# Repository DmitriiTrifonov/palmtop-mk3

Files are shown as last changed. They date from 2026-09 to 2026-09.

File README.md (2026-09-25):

# Palmtop Mk3

A clamshell that turns a Pixel 3a XL into a pocketable laptop-shaped terminal.
Third iteration, after Mk1 (Blender) and Mk2 (FreeCAD), neither of them published.

Same phone, new keyboard — a Jomaa KEYBOARD098RU salvaged from its folio case.

<p align="center">
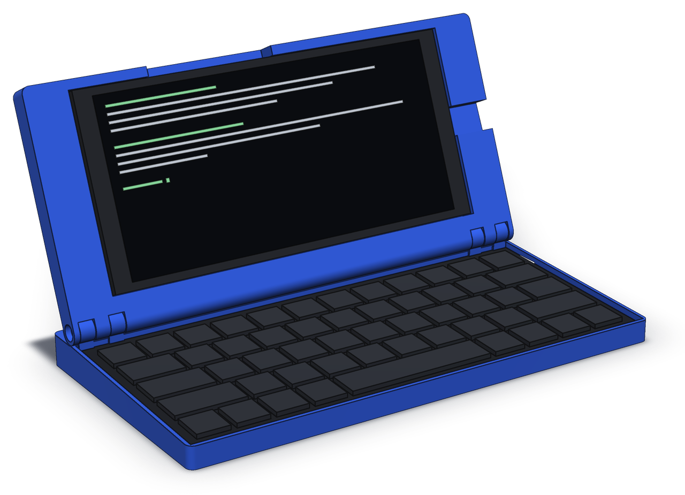
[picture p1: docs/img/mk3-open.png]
Palmtop Mk3 open at 112 degrees: a blue printed clamshell, the phone in the lid showing a terminal, the keyboard in the base
  
</p>

**The goal of Mk3 is to be as thin as possible.** Mk2 is roughly 32 mm closed;
Mk3's design point is 22.2 mm, with both components fully enclosed and the
keyboard never opened.

<p align="center">
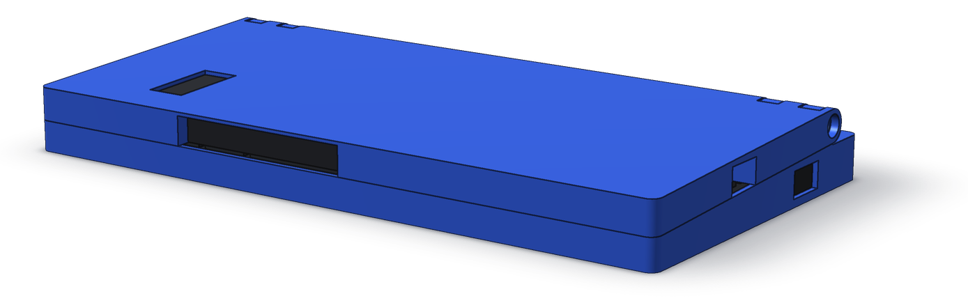
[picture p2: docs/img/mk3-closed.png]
Palmtop Mk3 closed, seen from the front right
  
  <br>
  <sub>Shut: 22.24 mm at the hinge, 18.26 at the front. Both renders come straight from the
  model via <code>cad/render.py</code>; the phone and keyboard are stand-ins built from
  their measured envelopes.</sub>
</p>

## Status

Measured, analysed, modelled, and now printing. The geometry is code — `cad/`
builds and self-verifies against the analyses — and the first printed coupons
caught two defects that no check could see, both of which are now checked for:
see [ADR-0010](docs/adr/0010-hinge-station-count.md).

**Design point: 22.24 mm closed at the rear, 18.26 at the front** — the keyboard
is a 2.64 deg wedge, so the closed device is one too.

| Doc | What it is |
|---|---|
| [requirements.md](docs/requirements.md) | Goals, constraints, acceptance criteria |
| [measurements.md](docs/measurements.md) | Every number, with a confidence tag |
| [analysis/thickness-budget.md](docs/analysis/thickness-budget.md) | Where the closed height goes, and three scenarios |
| [analysis/balance.md](docs/analysis/balance.md) | Whether the heavy lid tips it over, and what it costs to fix |
| [analysis/clamshell-geometry.md](docs/analysis/clamshell-geometry.md) | Why the lid is shallower than the base and the tail stays exposed |
| [plan.md](docs/plan.md) | Phases, critical path, and the five named risks |
| [parameters.md](docs/parameters.md) | Every driving dimension, paired with `cad/params.py` |
| [adr/](docs/adr/README.md) | Ten design decisions: six accepted, one rejected, three open |

## Findings so far

**Neither component gets thinner, so the skins had to go.** The keyboard shell is
9.52 mm and the phone 8.2 mm; together that is 90% of the budget and neither is
negotiable — [ADR-0002](docs/adr/0002-keyboard-integration-depth.md) keeps the
keyboard sealed and defers stripping it to Mk4. What remained were two 1.2 mm
skins: the lid's back and the base's floor. Deleting both is what gets the device
under 20 mm.

**Both skins were spent on enclosure, deliberately.** Neither was structurally
necessary: the keyboard's own bottom shell could have been the base's floor
(-1.2 mm), and the phone's own back could have been the lid's outer face
(-1.2 mm), for a 19.8 mm device with both components exposed.
[ADR-0008](docs/adr/0008-base-floor.md) and
[ADR-0004](docs/adr/0004-phone-retention.md) declined both. The result is 22.24 mm
with everything enclosed — a 30% reduction over Mk2 instead of 38%. That was the
trade, and it leaves only 0.26 mm against the current hard limit, which
[needs restating](docs/requirements.md#n1-needs-restating).

**The hinge is printed, not bought.** Holding the lid takes 0.10-0.12 N*m — the
very bottom of the commercial torque-hinge range, where Reell's scaled-down
consumer-electronics series starts at 0.11 N*m. Printed knuckles on two M3 bolted
stations deliver it at 22-25 N of clamp each, still a light load for an M3. The governing idea is that **the bolt sets deflection and a
compliant washer sets force**, so the setting is adjustable with a screwdriver
and survives PETG creep. Stations rather than a full-width rod, because racking
resistance comes from the span between the outermost points, not from continuity
— and a 193 mm printed barrel would bow. Two stations rather than three because
a bolt can only reach a station from outside the device: the lid's rounded rear
runs the full width along the hinge axis, so a centre station had no way in
([ADR-0010](docs/adr/0010-hinge-station-count.md)). No lead time, which took the longest
item off the critical path. Purchased torque hinges stay recorded as an upgrade
path in [ADR-0005](docs/adr/0005-hinge-mechanism.md).

**The tipping problem turned out to be free to fix.** The phone (167 g) outweighs
the keyboard (95 g) and the device tips past 127 deg of opening unaided. Fixing
it entirely — no tipping at any angle — costs 15 mm of rear setback, which is
zero mass and zero thickness — and the same 15 mm is where the hinge stations
stand. Nothing like the
substantial ballast that Mk2's `palmtop_weighted` name implies.

## Layout

```
docs/          requirements, measurements, analyses, ADRs
docs/img/      README renders, from cad/render.py
cad/           build123d model: params.py drives it, build.py checks and exports
export/        STL and STEP for printing, SVG drawings
```

## Licence

Copyright Dmitrii Trifonov 2026.

The design — the model in `cad/`, the files it exports, and the documentation — is
released under the [CERN Open Hardware Licence Version 2 – Strongly Reciprocal](LICENSE)
(CERN-OHL-S-2.0). Under this licence the Python model is the design's source: if
you adapt it, to a different phone or keyboard say, and distribute the result or
anything built from it, you share your modified source under the same terms.

Source location: <https://github.com/DmitriiTrifonov/palmtop-mk3>

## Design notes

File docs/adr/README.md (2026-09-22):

# Architecture decision records

One file per structural decision, written before the geometry is committed to
CAD. See [ADR-0001](0001-record-architecture-decisions.md) for why.

| # | Decision | Status | Blocked on |
|---|---|---|---|
| [0001](0001-record-architecture-decisions.md) | Record design decisions as ADRs | Accepted | — |
| [0002](0002-keyboard-integration-depth.md) | How deeply to integrate the keyboard | **Accepted** — stays sealed, stripping deferred to Mk4 | — |
| [0003](0003-lid-balance-strategy.md) | Keeping the device from tipping backwards | **Accepted** — 15 mm rear setback + empty ballast pocket |
| [0004](0004-phone-retention.md) | How the phone is held in the lid | **Accepted** — closed pocket with a rear wall | — |
| [0005](0005-hinge-mechanism.md) | Hinge mechanism | Proposed | Coupon 2.2 — measured torque of a printed bolted hinge |
| [0006](0006-rear-edge-io-vs-hinge.md) | Keyboard I/O on the hinge edge | **Rejected** — the premise was a misread photograph | — |
| [0007](0007-cad-toolchain.md) | CAD toolchain | **Accepted** — build123d, model is Python in `cad/` |
| [0008](0008-base-floor.md) | Base floor | **Accepted** — full 1.2 mm floor kept; Option E open | Task 0.4 (Option E only) |
| [0009](0009-closure-retention.md) | Keeping the device shut when closed | Proposed | Coupon 2.2 — does hinge torque survive 100 cycles |
| [0010](0010-hinge-station-count.md) | How many hinge stations, and how a bolt reaches its pocket | Proposed — two stations, heads outboard | First article — does the lid sag at mid-span |

## Dependency order

```
0002 (keyboard sealed, ACCEPTED)
   |
   +--> only two 1.2 mm skins left as thickness levers, both now spent:
   |        0008 (base floor, ACCEPTED: kept)
   |        0004 (lid rear wall, ACCEPTED: kept)   --> 22.24 mm
   |            |
   |            +--> 0008 Option E (0.8 ribbed floor) is the last 0.4 mm
   |
   +--> 0006 (rear I/O stays a live problem)
            |
   0005 (hinge) <--> 0003 (setback) <--> 0006 (rear I/O)
        all three resolve into one rear-edge cross-section
            |
            +--> 0009 (stays shut) rides on 0005's measured torque

0007 (toolchain) gates everything but depends on nothing
```

## The shape of the design as it stands

0002 fixed the keyboard as an untouchable 9.52 mm block, leaving two 1.2 mm skins
as the only thickness levers. 0008 spent one on an enclosed base; 0004 spent the
other on a protected phone back, the fingerprint reader it covers being unused.

The result is **22.24 mm** — a 30% reduction over Mk2 with both components fully
enclosed, rather than the 38% that was available with both exposed. That was the
trade, made twice and deliberately.

**It leaves 0.26 mm of margin against N1's hard limit of 22.5, which is not a
margin.** Two things follow: 0008 Option E (a 0.8 ribbed floor, stiffer than the
flat 1.2 it replaces) is now the project's only remaining reduction and should be
resolved early; and the hard limit itself needs restating, since 22.5 was derived
from an early estimate of this very scenario.

On balance, the two decisions nearly cancelled: 0008 added 26 g low, 0004 added
25 g high, and the device tips at 127 deg. A **15 mm** rear setback eliminates
tipping at any angle across the whole plausible mass bracket — 11 mm covered only
the expected case — and 0006 uses that tail as a shelf for the keyboard's
rear-edge I/O.

So the three open structural ADRs remain one problem: **the rear-edge
cross-section**, where the hinge, the setback and the keyboard's switch, LEDs and
USB-C all have to share the same 15 mm of depth.

0005 has since made that section easier in two ways. Its printed knuckles on
bolted stations have **no lead time**, so they no longer block the drawing; and
because the stations occupy points rather than the whole rear line, the gaps
between them are free for port tunnels. What is left blocking the cross-section
is a single measurement, task 0.1.

0009 turned out to need no hardware of its own. Holding the lid shut while
inverted takes the same 0.091 N*m as holding it at 90 deg — the moment arm is the
same in both cases — so the hinge torque F3 already demands satisfies F8 with
margin. Magnets stay recorded as insurance, with a note to check the phone's
magnetometer first.

One more consequence surfaced along the way and is written up in
[clamshell-geometry.md](../analysis/clamshell-geometry.md): with an inboard axis,
a lid the same depth as the base **does not open at all** — its rear overhang
drives straight into the setback tail. The lid is therefore 197 x 90 and the base
197 x 105, with the tail exposed even when shut, exactly as a laptop's hinge
region is. Full 0-180 deg remains available.

0010 came out of a question asked while looking at an assembly drawing: would the
bolt actually go in? It would not. The lid's rounded rear is a solid cylinder
coaxial with the hinge, so it blocks the bolt's path equally at every opening
angle, and the centre station had no path at all. Neither the interference check
nor the 0-180 deg sweep could see it — an unassemblable joint overlaps nothing.
The station count dropped to two and `build.py` gained a corridor check, next to
the connectivity check added the same day for the same class of blindness.

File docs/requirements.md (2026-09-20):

# Requirements

## Context

Palmtop Mk3 is the third iteration of a clamshell that turns a Pixel 3a XL into a
pocketable laptop-shaped terminal. Mk1 (`../pixel_palmtop`, Blender) and Mk2
(`../palmtop_mk2`, FreeCAD) both worked, but Mk2 is bulky: a 170 x 91.4 footprint
with a base part 23.35 tall and a lid part 18.21 tall.

Mk3 keeps the same phone and swaps in a much slimmer keyboard (Jomaa
KEYBOARD098RU, salvaged from its folio case).

## Primary goal

**Minimise closed thickness.** Every other property is negotiable against it,
within the constraints below.

## Functional requirements

| # | Requirement |
|---|---|
| F1 | Holds a Pixel 3a XL in landscape orientation in the lid, screen facing the keyboard when closed |
| F2 | Holds the Jomaa keyboard in the base |
| F3 | Opens and stays open, hands-free, at any angle within the supported range |
| F4 | Does not tip over backwards at any supported opening angle, on a desk |
| F5 | Keyboard USB-C reachable without disassembly. The power switch stays permanently ON and needs no access in normal use; the status LEDs are not required to be visible |
| F6 | Phone USB-C reachable for charging while the device is open and in use |
| F7 | **Relaxed.** The phone is taped into the lid, as Mk2's was, so it comes out with a pry and some patience rather than in 30 seconds. An accepted trade, not a requirement met — see [ADR-0004](adr/0004-phone-retention.md) |
| F8 | Stays shut when closed, including inverted in a bag — see [ADR-0009](adr/0009-closure-retention.md) |

## Non-functional requirements

| # | Requirement |
|---|---|
| N1 | Closed thickness at the thickest point: target <= 20.0, hard limit <= 22.5. Design point is **22.24** — the target is missed by 2.24 through two deliberate trades, [ADR-0008](adr/0008-base-floor.md) and [ADR-0004](adr/0004-phone-retention.md). **The hard limit needs restating** (see below) |
| N2 | Footprint: base ~197 x 105 including the 15 mm rear setback; lid ~197 x 90, ending at the hinge axis, leaving the tail exposed when closed (see [clamshell geometry](analysis/clamshell-geometry.md)) |
| N3 | Printable on a 256 x 256 bed without the base being split into multiple parts |
| N4 | Total mass <= 400. Currently ~374 as printed (~432 if it were solid) — measure against the slicer's figure, not `volume x density` |
| N5 | No custom electronics — keyboard and phone stay stock |
| N6 | Parametric CAD: all key dimensions driven from one table, so a different phone or keyboard is a re-parametrisation, not a redraw. Satisfied by [ADR-0007](adr/0007-cad-toolchain.md) — `docs/parameters.md` paired with `cad/params.py` |

## Explicit non-goals

- Modifying the phone or flashing anything on it
- Adding a trackpad, extra battery or any powered component
- Water or drop resistance beyond "survives being carried in a bag"

## Acceptance criteria

The build is done when all of the following hold on the physical device:

1. Closed thickness measured at the thickest point is within N1.
2. The open device does not tip backwards when the lid is at the maximum
   supported angle and the screen is tapped firmly at its top edge.
3. The lid holds position at 100, 120 and the maximum supported angle after
   50 open/close cycles.
4. Keyboard can be charged and power-cycled with the device fully assembled.
5. Phone can be charged with the device open and in use.
6. Phone can be removed and reinserted without damaging either the phone or the
   lid. Not quickly — F7 was relaxed when the phone went onto tape.

## N1 needs restating

The hard limit of 22.5 was written before any construction was chosen, as a round
number just above an early estimate of what is now the selected scenario. The
device has landed at 22.24, so the limit constrains with 0.26 mm of margin — and
it is constraining against a number derived from itself.

This matters because the contingency is real: if coupon 2.4 shows the base flexes
under typing, the floor goes from 1.2 to 2.0-2.5 and the device becomes 23.0-23.5.
There is no headroom to absorb that.

Two responses, not exclusive:

1. Pursue [ADR-0008](adr/0008-base-floor.md) Option E — a 0.8 floor ribbed into
   the keyboard's rim recess, which is *stiffer* than the flat 1.2 it replaces
   and gives back 0.4. This is the project's only remaining reduction.
2. Replace 22.5 with a limit that means something — a pocket, a bag sleeve, a
   number the owner actually cares about — rather than one back-derived from a
   spreadsheet.

**Open question for the owner:** what is the real ceiling?

## Scope boundary with Mk4

[ADR-0002](adr/0002-keyboard-integration-depth.md) keeps the keyboard sealed for
Mk3. Stripping it to its bare plate — worth an estimated 16.5-18.5 mm closed, but
irreversible on the only unit in hand — is deferred to Mk4, to be attempted once
a working Mk3 exists as a fallback. Mk3 must therefore leave the keyboard
removable without cutting anything.

## Open decisions

See [the ADR index](adr/README.md). ADR-0002 is settled; the remaining structural
decisions are not. The analyses in `docs/analysis/` exist to inform them.

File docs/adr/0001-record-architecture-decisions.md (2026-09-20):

# ADR-0001: Record design decisions as ADRs

- **Status:** Accepted
- **Date:** 2026-09-20

## Context

Mk1 and Mk2 exist only as CAD files. The reasoning behind their geometry — why
the footprint is 170 x 91.4, why the base is 23 mm tall, what the "weighted" in
`palmtop_weighted_mk2` was compensating for — is gone. Mk3 starts by re-deriving
things that were presumably already understood two iterations ago.

## Decision

Every structural decision for Mk3 is recorded as a numbered ADR in `docs/adr/`,
written before the geometry is committed to CAD. An ADR stays `Proposed` until
the supporting measurement or test print exists.

## Consequences

- A decision that is later reversed leaves a trail explaining why it was made,
  which is the expensive part to reconstruct.
- ADRs are immutable once `Accepted`. A changed mind is a new ADR that supersedes
  the old one, not an edit.
- Numbers quoted in an ADR must carry a confidence tag from
  [measurements.md](../measurements.md), so a decision resting on a guess is
  visibly resting on a guess.

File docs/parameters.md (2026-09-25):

# Parameters

**Generated from `cad/params.py` — do not edit by hand.**
Regenerate with `.venv/bin/python cad/gen_params_doc.py`.

The Python is the source of truth; this file exists so the numbers are readable
and reviewable in a diff, as [ADR-0007](adr/0007-cad-toolchain.md) requires.

All lengths mm, masses g, angles deg.

Status: `M` measured · `S` from spec · `D` decided in an ADR · `C` calculated
from others here · `A` assumed, not yet verified

---

## Keyboard — Jomaa KEYBOARD098RU

| Name | Value | St | Note |
|---|---|---|---|
| `kbd_span_x` | 194 | M |  |
| `kbd_depth_y` | 86.25 | M |  |
| `kbd_h_rear` | 9.52 | M | thickest, rear of the wedge |
| `kbd_h_front` | 5.54 | M | thinnest, front |
| `kbd_keycap_rear` | 1.82 | M |  |
| `kbd_keycap_front` | 1.82 | M | owner: same as rear |
| `kbd_mass` | 95 | M |  |
| `kbd_rim_width` | 1.68 | M | perimeter rim on the underside |
| `kbd_wedge_angle` | 2.642 | C | atan((h_rear - h_front) / depth) |

## Keyboard USB-C — on the RIGHT SIDE face, not the rear edge

| Name | Value | St | Note |
|---|---|---|---|
| `kbd_usbc_rear_inset` | 8 | M | rear edge to the near end of the connector |
| `kbd_usbc_z_bottom` | 3 | M | opening's lower edge above the rest plane |
| `kbd_usbc_z_top_inset` | 2 | M | opening's upper edge below the top of that face |
| `kbd_usbc_face_h` | 8.9432 | C | the side face is a wedge |
| `kbd_usbc_h` | 3.9432 | C | derived opening height |
| `kbd_usbc_w_ASSUMED` | 9 | A | task 0.1 — the last measurement outstanding |
| `usbc_centre_y` | 75.65 | C | in device coordinates |
| `usbc_centre_z` | 6.1716 | C |  |
| `usbc_cut_w` | 13 | D | opening in the base's right wall, along Y |
| `usbc_cut_h` | 7.5 | D | along Z |

## Phone — Pixel 3a XL

| Name | Value | St | Note |
|---|---|---|---|
| `phone_x` | 160.1 | S | long axis, horizontal in the lid |
| `phone_y` | 76.1 | S |  |
| `phone_z` | 8.2 | S | body, excluding the camera bump |
| `phone_mass` | 167 | S |  |
| `phone_front_wall` | 4 | D | biased forward so the buttons are reachable |
| `tape_t` | 1 | D | double-sided tape, on the pocket's SIDE walls |
| `button_win_x0` | -48.6 | M | button window, from Mk2's STL |
| `button_win_x1` | 5 | M |  |
| `cam_x0` | -69.8 | M | camera cutout, from Mk2's STL |
| `cam_x1` | -58.6 | M |  |
| `cam_from_edge0` | 8.85 | C | referenced to the phone's own button-side edge |
| `cam_from_edge1` | 32.05 | C |  |
| `phone_usbc_cut_w` | 12 | D | phone's own port, lid's right wall |
| `phone_usbc_cut_h` | 7 | D |  |

## Materials and clearances

| Name | Value | St | Note |
|---|---|---|---|
| `mat_density` | 0.00127 | S | g/mm3, PETG, SOLID — see the note in params.py |
| `wall_t` | 1.6 | A |  |
| `clr_kbd` | 0.3 | A | per side, depth |
| `clr_kbd_x` | 0.6 | M | per side, span: absorbs measured print shrinkage |
| `clr_phone` | 0.3 | A | per side |
| `keycap_gap` | 0.3 | D | held open by the base's rim, not by a liner |
| `corner_r` | 3 | D | outer vertical corners |

## Base

| Name | Value | St | Note |
|---|---|---|---|
| `base_floor_t` | 1.2 | D | ADR-0008 |
| `base_x` | 198.4 | C | kbd_span_x + 2*(wall_t + clr_kbd_x) |
| `base_depth_to_axis` | 90.05 | C |  |
| `hinge_setback` | 15 | D | ADR-0003 |
| `base_y` | 105.05 | C | base_depth_to_axis + hinge_setback |
| `foot_dia` | 10 | D | locating recesses for bumpons |
| `foot_recess` | 0.4 | D |  |
| `foot_y_rear` | 99.05 | C | sets the tipping contact line — see ADR-0003 |
| `foot_y_front` | 8 | D |  |
| `foot_inset_x` | 12 | D |  |

## Lid

| Name | Value | St | Note |
|---|---|---|---|
| `lid_rear_wall` | 1.2 | D | ADR-0004, closed pocket |
| `lid_x` | 198.4 | C | matches base_x |
| `lid_y` | 90.05 | C | ends at the hinge axis |
| `lid_t` | 9.4 | C | lid_rear_wall + phone_z |
| `lid_rear_radius` | 4.7 | C | half the lid thickness |

## Derived stack

| Name | Value | St | Note |
|---|---|---|---|
| `parting_rear` | 12.54 | C | top of the keycaps |
| `parting_front` | 8.56 | C |  |
| `rim_rear` | 12.84 | C | where the lid lands |
| `rim_front` | 8.86 | C |  |
| `closed_h_rear` | 22.24 | C | **the N1 number** |
| `closed_h_front` | 18.26 | C |  |
| `close_tilt` | 2.5307 | C | the lid shuts nose-down onto the wedge |

## Hinge

| Name | Value | St | Note |
|---|---|---|---|
| `hinge_axis_y` | 90.05 | C |  |
| `hinge_axis_z` | 17.54 | C | lid mid-thickness, NOT the parting plane |
| `hinge_torque_req` | 0.091 | C | N*m at 90 deg |
| `knuckle_od` | 9 | D | capped by the lid's thickness at the axis |
| `knuckle_id` | 3.5 | D | M3 clearance |
| `knuckle_clr` | 0.2 | D | per face |
| `station_outer_w` | 6 | D | each base knuckle |
| `station_inner_w` | 5.8 | D | the lid knuckle |
| `station_w` | 18.2 | C |  |
| `station_relief_r` | 5.7 | D | wider than lid_rear_radius so a post can exist |
| `post_half_y` | 2.5 | D |  |
| `nut_af` | 5.7 | D | M3 nut across flats |
| `nut_depth` | 4.3 | D |  |
| `head_dia` | 5.8 | D |  |
| `head_depth` | 3.8 | D | head plus a wave washer |

## Masses and balance — estimates, risk R3

| Name | Value | St | Note |
|---|---|---|---|
| `infill_chunky` | 0.42 | A | chunky blocks take infill; thin walls print solid |
| `r_lid` | 45 | A | superseded in build.py by a value derived from the geometry |
| `d_base` | 41 | A | keyboard mass is rear-biased |

## Hinge stations

At X = -87.5, 87.5, span 175.0 mm between the outermost.

## Still blocked

| Parameter | Waiting on |
|---|---|
| `kbd_rim_recess` | task 0.4 |
| `phone_camera_bump` | task 0.6 |

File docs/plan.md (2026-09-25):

# Plan

## Where the project stands

Measurements for the keyboard and phone are in hand, two analyses are written,
and the first decision is made.

Five decisions are made, and the model is now code.

**[ADR-0002](adr/0002-keyboard-integration-depth.md): the keyboard stays sealed.**
Stripping it to its plate — worth an estimated 16.5-18.5 mm closed, but
irreversible on the only unit in hand — is deferred to Mk4. That fixed 9.52 mm of
the stack as untouchable and left exactly two 1.2 mm skins as thickness levers.

**[ADR-0008](adr/0008-base-floor.md): the base keeps a full floor**, for
enclosure and stiffness. **[ADR-0004](adr/0004-phone-retention.md): the lid keeps
a rear wall**, for rear protection — the fingerprint reader it covers will not be
used. Both levers spent. Design point:

```
   rear edge   22.24 mm      front edge   18.26 mm
   (Mk2 is roughly 32 mm, to be confirmed with calipers)
```

A 30% reduction over Mk2 with both components fully enclosed, rather than the 38%
that was available with both exposed. **That leaves 0.26 mm against N1's hard
limit of 22.5, which is not a margin** — see
[requirements.md](requirements.md#n1-needs-restating).

On balance the two decisions nearly cancelled — 26 g added low, 25 g added high —
and the device tips at 127 deg. A **15 mm** rear setback eliminates tipping at any
angle across the whole plausible mass bracket, and
[ADR-0006](adr/0006-rear-edge-io-vs-hinge.md) uses that tail as an I/O shelf. See
[balance.md](analysis/balance.md).

Five ADRs remain open. Four are blocked on measurements rather than preference.

## Phase 0 — close the blocking unknowns

Nothing in CAD should start before these exist. Each unblocks a specific ADR.

| # | Task | Unblocks |
|---|---|---|
| 0.1 | ~~USB-C position~~ done — right side face, 8 mm back from the rear edge. Still needed: the port **opening's width**, and the overmould size of the cable actually used | sizes the opening in the base's right wall |
| 0.4 | Measure the bottom-rim recess depth at 6+ points around the perimeter | ADR-0008 Option E — **the only remaining thickness reduction** |
| 0.5 | Measure the physical Mk2's closed height with calipers | benchmark for N1 |
| ~~0.6~~ | Superseded — Mk2's camera cutout measured off its STL and transferred. It is a through-hole, so the bump height never mattered | — |
| 0.7 | Buy M3 x 16 socket caps (DIN 912), M3 nylon-insert nuts (DIN 985 — the pocket is sized for their 4.00 height, and a plain nut would need a threadlocker nobody can re-apply once the lid is in) and a range of compliant elements — 3 x 1 NBR O-rings, TPU washers — so coupon 2.2 tunes torque by swapping rather than reordering. DIN 137B wave washers are 6.0 OD and do not fit the Ø5.80 head pocket | ADR-0005, ADR-0010 |
| ~~0.8~~ | Superseded — the phone is taped in, as Mk2's was, so there are no retention lips to size | — |
| 0.9 | Check the phone's magnetometer against a loose magnet at ~8 mm | ADR-0009 Option B |
| ~~0.10~~ | Superseded — Mk2's button window measured off its STL and transferred; same phone, same orientation, centred in X in both | — |
| 0.11 | Look at how Mk2's lid treats its top edge around the buttons — relieved, or continuous | ADR-0004; confirms Mk2's no-accidental-press evidence transfers |

Task 0.4 is back on the critical path. With both skins spent, scenario A-thin — a
0.8 floor ribbed into the keyboard's rim recess, taking 22.24 to 21.84 — is the
only reduction left in Mk3, and the 0.26 mm of margin against the hard limit
makes it worth having. It is also data Mk4 will want.

Checking whether a spare keyboard is purchasable is off the critical path, but
still worth knowing for Mk4.

**Owner decision needed, not a measurement:** what the real thickness ceiling is.
See [requirements.md](requirements.md#n1-needs-restating).

Hinge sourcing used to be the longest item here. It is gone:
[ADR-0005](adr/0005-hinge-mechanism.md) now recommends printed knuckles on
bolted stations with a compliant element setting the friction force, all of it
stock hardware. Purchased torque hinges remain
a defined upgrade path, with a sourcing spec recorded in that ADR.

## Risks

Named explicitly, because the task table above lists unknowns that are cheap to
close and says nothing about the ones that are not.

### ~~R1 — the rear edge may not have room for both the hinge and the USB-C~~

**Gone.** The USB-C is on the keyboard's right side face, not on the rear edge,
so the hinge has all 193 mm of that edge to itself. The stations are symmetric at
±88 and the span between them is 1.5% short of ideal rather than 10.8%.

The risk was real given what was believed at the time, and it was tracked and
mitigated correctly. It was also founded on a misread photograph — see
[ADR-0006](adr/0006-rear-edge-io-vs-hinge.md), which is kept as the record.

### R2 — no thickness margin at all

22.24 against a 22.5 hard limit. If coupon 2.4 shows the base flexes under
typing, the floor goes to 2.0-2.5 and the device becomes 23.0-23.5. Nothing
absorbs that.

Mitigated by [ADR-0008](adr/0008-base-floor.md) Option E (worth 0.4 and
*stiffer* than the floor it replaces) and by restating N1's ceiling — see
[requirements.md](requirements.md#n1-needs-restating).

### R3 — the balance analysis rests on estimated masses

**Partly realised already.** The first parametric model showed the hand estimates
were roughly half of reality — the lid's 18 mm-wide solid side rings had never
been counted. The masses are now a bracket (lid 40-83 g, base 42-72 g) rather
than a guess, and [ADR-0003](adr/0003-lid-balance-strategy.md) went from 11 mm of
setback to 15 to cover the whole of it.

What remains is that the bracket is itself estimated, and `r_lid` and `d_base`
still are too. The keyboard's internal mass distribution is not modelled at all,
and it is 69% of the base mass.

Mitigated by coupon 2.5 (weigh and re-run `cad/params.py`) and by carrying the
ballast pocket as a correction lever.

### R4 — the Mk2 benchmark was never measured

"Roughly 32 mm" is an estimate from a photograph. Every "-30% vs Mk2" claim in
this repo rests on it. Task 0.5 fixes it for the price of picking up calipers.

### R6 — knuckle print orientation conflicts with printing the base as one part

A 197 x 105 base realistically prints floor-down, which puts the hinge knuckles'
layer lines across the bending load they carry — the weak direction, and the only
direction the lid's weight acts in. [ADR-0005](adr/0005-hinge-mechanism.md)
Option G (separate bolted knuckle blocks) is the way out, at the cost of parts
and of play accumulating across two bolted interfaces.

Mitigated by printing the knuckle section both ways in coupon 2.2 and loading
both to failure.

### R5 — single-point measurements

Keycap protrusion (1.82) and the bottom-rim recess (<1 mm) were each measured at
one point and are used as if uniform. Tasks 0.3 and 0.4.

## Unassigned detail problems

Real work with no owner and no ADR. None blocks the cross-section, but all of
them have to exist before Phase 3.

| Problem | Note |
|---|---|
| Local gussets under the hinge stations | The base's rear pocket wall is 12.54 tall at 1.6 thick and takes point loads ([ADR-0005](adr/0005-hinge-mechanism.md)) |
| Where the opening grip goes | Mk2 had no accidental-press problem with the same layout, so this is a styling choice rather than a fix |
| Felt liner, now optional | No longer sets the keycap gap — the base's rim does. Worth having as screen protection |
| Styling of the exposed tail | [clamshell-geometry.md](analysis/clamshell-geometry.md) makes it an exterior surface; better decided than discovered |

## Phase 1 — decide

Close [ADR-0007](adr/0007-cad-toolchain.md) immediately; it depends on nothing.

Then resolve **0003, 0005 and 0006 as a single rear-edge cross-section drawing**,
not as three separate decisions. They share the same 10 mm of depth and the same
9.5 mm of height: the hinge, the setback tail and the keyboard's switch, LEDs and
USB-C all have to coexist in that section.

[ADR-0004](adr/0004-phone-retention.md) can close in parallel, after coupon 1.3.

## Phase 2 — coupons before the whole thing

Small test prints, each answering one question.

| # | Coupon | Question it answers |
|---|---|---|
| 2.1 | Rear-edge cross-section, 40 mm wide, both halves | Does hinge + setback + I/O access actually fit in the section, and does the lid open? **Do this one first** (R1) |
| 2.2 | Printed two-station knuckle section with M3 bolts and compliant washers | What torque does it actually produce, measured with a spring scale? Is it adjustable by feel? How much is lost over 100 cycles? Does it rack? |
| 2.3 | Lid pocket corner, full thickness | Does the phone seat and stay in? Does the camera cutout clear the bump? Can the phone be pushed back out? |
| 2.4 | Base pocket, full 193 x 86 footprint but short, printed at both 1.2 and 0.8+ribs | Does the keyboard seat and stay in? Does the floor flex under typing? Is the 0.8 ribbed floor sound (scenario A-thin)? |
| 2.5 | Weigh 2.3 and 2.4, extrapolate to full shells | Replaces the `E`-confidence masses in the balance analysis (R3) |

Re-run the balance numbers after 2.5. If they move materially, revisit ADR-0003
before Phase 3 rather than after.

## Phase 3 — v1

Full base and lid, assembled with the real keyboard and phone. Expect this to be
wrong in at least two places; the point is to find out which two.

## Phase 4 — validate

Against the acceptance criteria in [requirements.md](requirements.md). The ones
that will actually bite:

- Closed thickness against whatever N1's restated ceiling turns out to be
- Tip test at maximum opening angle with a firm tap on the top of the screen
- 50 open/close cycles, then re-check that the lid still holds 120 deg
- Keyboard removable without cutting anything — Mk4 depends on it
- Phone temperature under sustained use, with its back fully enclosed

## Phase 5 — publish

Mk2 was published on MakerWorld (`../palmtop_mk2/maker_world/`). Same for Mk3:
STL + STEP + photos, and a link back to this repo for the reasoning.

## Critical path

```
0.1 I/O positions    --> ADR-0006 --+--> 2.1 rear cross-section --> Phase 3
                         ADR-0003 --+
                         ADR-0005 --+ (2.2 validates, does not block)
0.4 rim recess depth --> ADR-0008 opt E --> 2.4 base floor --> Phase 3
```

**Nothing on this path has a lead time any more.** Task 0.1 is now the only thing
blocking the rear-edge cross-section, and it is a caliper and ten minutes. Task
0.4 is the same, and it gates the only millimetres left in the budget. Both
should happen next.

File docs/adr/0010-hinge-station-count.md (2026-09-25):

# ADR-0010: Two hinge stations, not three

- **Status:** Proposed — the span stiffness of two stations is what the first article decides
- **Date:** 2026-09-22
- **Decides:** how many stations the hinge has, and how a bolt head reaches its pocket

## Context

ADR-0005 put three bolted stations on the hinge line, at X = -87.5, 0 and +87.5.
The count was chosen for load sharing across a 197 mm span. Nobody checked
whether a bolt could physically get into the middle one.

It cannot. The lid's rear edge is rounded on a radius equal to its own
half-thickness, 4.70, struck about the hinge axis. That rounding is not
decoration — it is what makes the 0-180 deg sweep clean, and it was added
precisely to stop the lid's rear corner driving into the setback tail. But it
is a **solid cylinder, Ø9.40, coaxial with the hinge, running the full 196.8**.
Between stations it fills the axis completely.

Measured as the obstruction inside a Ø5.6 x 30 corridor running out from each
pocket — 0 mm³ would be clear, 739 mm³ is solid:

| Station | Head corridor | Nut corridor |
|---|---|---|
| X = -87.5 | 716.7 | 24.0 |
| X = 0.0 | 716.7 | 716.7 |
| X = +87.5 | 24.0 | 716.7 |

The 24.0 mm³ figure is the annulus of lid left around the Ø3.5 bore over the
1.6 mm of lid standing outboard of a station. A Ø5.5 head does not pass a Ø3.5
hole. The 716.7 figures are 87 mm of solid lid.

Two properties of the obstruction matter more than its size:

- **Opening the lid does not clear it.** The blockage is coaxial with the axis
  the lid rotates about, so it occupies the same corridor at every angle. The
  numbers above are identical at 0 deg and at 120 deg.
- **Nothing in the check suite could see it.** Closed interference and the
  0-180 deg sweep both ask whether two solids overlap. An unassemblable joint
  overlaps nothing — the parts simply cannot be brought together in that order.

The nut is recoverable: its pocket is a hex socket, so it can be dropped in
before the lid is nested and is captive thereafter. Only the **bolt** needs a
clear axial path from outside the device.

## Options

### Option A — two stations at the ends, heads outboard

Drop the centre station. Keep ±87.5. Orient each station's fasteners so the head
pocket faces **outboard** and the nut pocket inboard, and bore Ø6.40 through the
1.6 mm of lid standing outboard of each station so the head can pass.

| Pros | Cons |
|---|---|
| No new parts, no new fasteners, no change to how either shell prints | Two hinge points across 197 mm instead of three |
| Both corridors measure 0.0 mm³ clear, at every opening angle | Mid-span lid stiffness becomes a thing to verify rather than assume |
| The arrangement every laptop uses | |

### Option B — three stations, the centre one a separate bolted block

The centre station's knuckles become their own printed part. The M3 stack is
assembled off the device and the block is then fastened down into the tail.
This is ADR-0005's Option G, applied to one station rather than all three.

| Pros | Cons |
|---|---|
| Keeps three points of support | A new part, its own fasteners, its own seating tolerance |
| Assembly access stops being a constraint on the hinge line at all | The block's fixing has to carry hinge moment through a printed interface |
| | Solves a problem that may not exist |

### Option C — bore an access channel along the whole hinge line

Open the lid's rear cylinder to Ø6.40 for its full width so a head can travel to
any station.

| Pros | Cons |
|---|---|
| Station count stays free | A 197 mm horizontal bore, unprintable without gutting the rear |
| | Leaves ~1.5 mm of wall on the one feature that carries the whole lid |
| | Still too small for a nut across corners (6.35) |

Rejected on printability alone.

## Decision

**Option A, provisionally** — two stations, heads outboard, with the span
stiffness treated as an open question rather than a settled one.

Option B solves a problem that has not been shown to exist. The cheapest way to
find out whether it exists is to print the two-station lid, hang the phone in it
and see whether the middle sags; if it does, Option B is still there and we will
have a measurement instead of an argument.

## Consequences

The bolt head corridor is now a **check in `build.py`**, not a thing to remember.
It sits with the connectivity check added the same day, after a lid printed as
four solids because nothing asked whether a part was one solid. Both failures
share a shape: the model was geometrically correct and physically impossible, and
the suite only knew how to ask geometric questions.

`fasteners()` is no longer symmetric — it mirrors on `outboard(x0)`. A station
added at X = 0 in future will silently get an arbitrary orientation and an
obstructed corridor; the access check is what will catch it.

Masses barely move: one station less is 431.0 g solid, 373.7 g printed, against
the 400 g budget in N4. Tipping margins stay above 1 at 150 and 180 deg on both
estimates.

**Each station now carries half the hinge torque, not a third** — and the
torque itself has grown. ADR-0005 sized it at 0.091 N*m from a 207 g lid at
45 mm; the model now gives 219-250 g (printed estimate to solid, phone
included) at an arm of 47.70 mm:

```
device       0.219..0.250 kg * 9.81 * 0.0477 m  =  0.103..0.117 N*m
per station                                     =  0.051..0.058 N*m
```

The axial clamp that delivers it — PETG on PETG at mu 0.35, two sliding faces
per station, r_eff 3.33 mm for a Ø9.00 face around a Ø3.5 bore — is **22-25 N
per station**, up from ADR-0005's 8.8. Still small for an M3, but no longer an
order of magnitude below what a 3 x 1 NBR ring gives at 20 % compression, so
coupon 2.2's measurement now decides something rather than confirming it.

On the one-station coupon, lid held horizontal, that requirement is **58-66 g
hung at the lid's front edge**, 90.05 mm from the axis. ADR-0005's 1x-3x
acceptance window becomes roughly: must hold 66 g, should slip before ~175 g.
The coupon lid's own ~15 g adds about 7 g-equivalent at the edge, which the
figures ignore, so they err on the demanding side.

**To revisit if the first article sags:** Option B, for the centre station only.
The number that settles it is deflection at mid-span with the phone's 167 g in
the lid, at full opening, measured against the base's rim.

Supersedes the station count in [ADR-0005](0005-hinge-mechanism.md); the
mechanism itself — printed knuckles, bolted, elastomer setting the force — is
unchanged.

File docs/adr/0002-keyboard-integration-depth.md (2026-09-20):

# ADR-0002: How deeply to integrate the keyboard

- **Status:** Accepted
- **Date:** 2026-09-20
- **Decides:** N1 (closed thickness). This is the highest-leverage decision in
  the project and every other ADR depends on its outcome.

## Context

Per the [thickness budget](../analysis/thickness-budget.md), the keyboard shell
is 9.52 mm of a 20-22 mm closed stack, and the phone is another 8.2 mm, fixed by
N5. Between them that is roughly 90% of the budget. Walls, clearances and keycaps
together are under 5 mm, so the keyboard shell is the only term large enough to
change the outcome by itself.

There is **one** keyboard. Its folio case is already destroyed, so a failed
teardown means buying another unit and losing the measurements this project is
built on.

Unknown, and decisive: the thickness of the keyboard's own bottom shell, of the
flat plate/PCB/scissor stack, and where the battery sits. The 2.64 deg wedge may
be pure shell geometry (in which case removing the shell removes 4 mm at the
rear) or it may follow a rear-mounted battery (in which case it removes almost
nothing).

## Options

### Option A — keyboard stays a sealed module

The keyboard drops into a pocket in the base as bought, retained by its own
perimeter rim and a printed lip. Nothing is opened.

| Pros | Cons |
|---|---|
| Zero risk to the only keyboard | Closed height floors out at 19.84 mm, and only if both skins are deleted too — 21.04 as actually built |
| Keyboard remains a replaceable part | The 2.64 deg wedge forces a wedge-shaped closed device |
| Its I/O keeps working exactly as designed | Rear I/O stays on the hinge edge (see ADR-0006) |
| Fastest path to a working Mk3 | Carries the shell's dead air and wedge into the stack |

### Option B — remove the bottom shell only

Split the keyboard's clamshell, discard its bottom half, and let the printed base
floor serve as the keyboard's bottom. The plate, PCB, battery and top shell (the
part that holds the key field) stay together.

| Pros | Cons |
|---|---|
| Saves the bottom shell thickness, est. 1.2-1.5 mm | Requires the printed floor to be stiff enough for typing, so it grows to 2.0-2.5 mm and gives ~1 mm back |
| Reversible-ish: the keyboard still works standalone if remounted | Net saving may be near zero |
| Low risk compared to C | Exposes the PCB to the base cavity; needs an insulating layer |

### Option C — strip to the plate and rebuild the wedge as a fold-out foot

Discard both shells. Mount the plate/PCB/battery directly into the printed base.
The typing angle no longer comes from the keyboard's wedge but from a fold-out or
removable rear foot, which sits *outside* the closed stack.

| Pros | Cons |
|---|---|
| The only path to <= 20 mm; est. 16.5-18.5 mm | Irreversible, and there is no second keyboard |
| Removes the wedge from the closed stack entirely | Saving is unverified — collapses if the battery is rear-mounted and thick |
| Frees the rear edge, dissolving the ADR-0006 conflict | The base must now provide scissor-plate rigidity, key retention and switch/LED/port mounting |
| Closed device becomes a flat slab rather than a wedge | Much more CAD and several more test prints |
| | Fold-out foot is another mechanism to design and another failure point |

### Option D — stage it: build A first, then C

Build and ship a working Mk3-A with the keyboard intact. Only then, with a proven
lid, hinge and balance, open the keyboard and produce an Mk3-C base that drops
into the same lid.

| Pros | Cons |
|---|---|
| Never blocks on the irreversible step | Two base designs to model and print |
| The teardown happens with a known-good reference device in hand | Target thickness is not met on the first build |
| If C fails, A still exists and is already assembled | Lid/hinge must be designed to accept both bases from the start |

## Decision

**Option A — the keyboard stays a sealed module.** Option C is deferred to Mk4.

The reasoning: a closed height around 20 mm is acceptable for Mk3, and scenario
B+ in the [thickness budget](../analysis/thickness-budget.md) reaches 19.84 with
the keyboard untouched by deleting the base floor instead. That makes the
remaining 2-3 mm that Option C would buy an expensive marginal gain — paid for
with the only keyboard in existence, on an estimate that is still a guess.

The right time to spend that risk is when there is a working Mk3 to fall back on
and the internal stack has been measured on a unit that is no longer critical.
That is Mk4.

This is Option D from the list above, with the second stage renamed to a separate
project rather than a later phase of this one.

## Consequences

- The rear edge keeps the keyboard's switch, LEDs and USB-C, so
  [ADR-0006](0006-rear-edge-io-vs-hinge.md) stays a live problem and must be
  solved rather than designed around.
- The 9.52 mm shell and the 2.64 deg wedge are fixed inputs. The closed device
  will be a wedge, ~17.1 at the front and ~21.0 at the rear.
- With the keyboard fixed, the only thickness levers left are the two 1.2 mm
  skins. [ADR-0008](0008-base-floor.md) kept the base floor, so the lid's back
  skin in [ADR-0004](0004-phone-retention.md) is the last one.
- Closed height lands at 21.04, over the N1 target of 20.0 and inside the 22.5
  hard limit.
- The keyboard must not be opened during Mk3. Any task that requires knowing its
  internal stack is out of scope, including relocating its I/O by wiring
  (ADR-0006 Option D is therefore unavailable).
- Mk4 inherits this repo's measurements and analyses. The teardown data it needs
  is listed under "Not yet known" in [measurements.md](../measurements.md).

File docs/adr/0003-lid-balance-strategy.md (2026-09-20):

# ADR-0003: How to keep the device from tipping over backwards

- **Status:** Accepted
- **Date:** 2026-09-20
- **Decides:** F4

## Context

The phone weighs 167 g and the keyboard 95 g, so the mass is in the lid. Mk2
addressed this with ballast — the file is literally named
`palmtop_weighted_mk2` — and Mk3's keyboard is lighter still.

The full derivation is in [balance.md](../analysis/balance.md). The load-bearing
results, with the hinge on the rear edge and no mitigation at all:

| Construction | Tips at |
|---|---|
| **Floored base + closed-back lid (137 / 207 g) — selected** | **127 deg opening** |
| Floored base + frame lid (137 / 182 g) — rejected | 133 deg opening |
| Frame base + frame lid (111 / 182 g) — rejected | 124 deg opening |

Both construction decisions moved this, in opposite directions.
[ADR-0008](0008-base-floor.md) kept the base floor, adding 26 g low down.
[ADR-0004](0004-phone-retention.md) kept the lid's rear wall, adding 25 g high
up. The second slightly outweighs the first, and the design lands where it
started.

So the problem is real but much smaller than it feels. Normal laptop use is
100-120 deg, which the bare design already survives; what it lacks is margin for
tapping the screen, bumping the desk, and reclining for reading.

Design target for this ADR: **stable to 150 deg opening**, i.e. `theta = 60 deg`
from vertical.

## Options

### Option A — rear setback

Move the hinge axis forward of the base's rear edge so the base extends behind
it as a tail, moving the tipping fulcrum backwards. This is what laptops do.

Required setback for 150 deg: **7.1 mm** on the working mass estimates, and
**10.8 mm** to make tipping impossible at any angle.

Those figures moved once `cad/massing.py` measured the real shells. The hand
estimates this analysis started from were about half of reality — the lid's
18 mm-wide solid side rings were never counted — so the masses are now a
*bracket*, 40-83 g for the lid and 42-72 g for the base, and the required setback
is a range rather than a number:

| Mass case | `s` to never tip |
|---|---|
| both light | 10.8 mm |
| both solid | 10.6 mm |
| working values | 10.8 mm |
| **heavy lid, light base** | **14.6 mm** |
| light lid, heavy base | 6.6 mm |

11 mm covers the expected cases and fails the worst one. **15 mm covers the whole
bracket.**

| Pros | Cons |
|---|---|
| Zero mass, zero thickness, zero parts | Adds 15 mm of footprint depth (90 -> 105) |
| At 15 mm it is elimination across the entire mass bracket, not just the expected case | Only ~7 mm is earned by the expected case; the rest buys insurance against R3 |
| Works identically at every opening angle | The tail is an overhang that must still print well |
| Also gives the rear I/O somewhere to breathe (ADR-0006) | Interacts with the hinge geometry; cannot be bolted on later |

### Option B — dense ballast at the front lip

A steel strip in the front wall of the base, ~82 mm forward of the hinge.

Required mass for 150 deg: **30 g** on the working estimates. With 15 mm of
setback in, no ballast is needed in any case in the bracket — which is precisely
why the pocket should still exist, empty, since the bracket itself is the thing
that might be wrong.

| Pros | Cons |
|---|---|
| Tunable after the fact, without changing geometry | Adds 30 g to a 400 g budget (N4) |
| Sits in the front of the wedge, where the closed stack is 15.9 against the governing 19.8 — so it costs no closed height | Needs a sourced strip cut to size, or a pocket for coins/bolts |
| Makes the device feel solid rather than hollow | Ballast is dead weight in a project whose goal is minimalism |
| Removable for tuning during bring-up | If glued in, a later rebalance means destroying the base |

### Option C — hard stop at ~120 deg

A mechanical stop in the hinge that never lets the lid reach an unstable angle.

| Pros | Cons |
|---|---|
| Free, and cannot be got wrong | Cannot recline the screen for reading or for a low viewing position |
| Removes the failure mode entirely rather than managing it | Does nothing for lap use, where there is no flat contact line anyway |
| | Feels like a limitation rather than a design |

### Option D — lid tail resting on the desk

Extend the lid below the hinge axis so that past ~110 deg its lower edge touches
the desk behind the device, converting the lid from a cantilever into a strut.

| Pros | Cons |
|---|---|
| Zero mass; stability improves as the lid reclines further, the opposite of the usual behaviour | The tail is visible and adds to the closed footprint or the closed thickness |
| Fully supports very reclined angles | Only engages past a certain angle, so it does not help the 100-130 deg band |
| | Scratches the desk unless padded |

### Option E — A + B: setback as structure, ballast pocket as trim

Design in the setback, and add an empty ballast pocket in the front of the base
that can be loaded during bring-up if the real masses differ from the estimates.

| Pros | Cons |
|---|---|
| The structural answer costs nothing; the ballast is only spent if needed | Slightly more CAD |
| Absorbs the fact that every shell mass in the analysis is an estimate | Pocket is wasted volume if never used |

## Decision

**Option E: a 15 mm rear setback, plus an empty ballast pocket in the front of
the base.**

15 rather than the 11 an earlier draft proposed. The reason is the mass bracket
above: 11 mm is derived from the *expected* masses, and those masses turned out
to be the weakest numbers in the project — the first parametric model showed the
hand estimates were roughly half of reality. 15 mm is the figure that holds
across the whole plausible bracket, including the case where the lid ends up
heavy and the base light.

The extra 4 mm is 4 mm of footprint depth and nothing else: no mass, no
thickness, no parts. Against that, the alternative is discovering after assembly
that the device tips and having no lever left but ballast, which adds mass in a
device whose whole point is being small.

The ballast pocket stays even though no case in the bracket now needs it. The
bracket is itself an estimate, and the pocket is the only correction that still
works after the geometry is cut.

## Consequences

- Base footprint becomes **196.8 x 105.05**; the lid stays 196.8 x 90.05 and ends
  at the axis, per [clamshell-geometry.md](../analysis/clamshell-geometry.md).
- The hinge axis is no longer on the rear edge of the base, which changes the
  hinge mounting geometry — [ADR-0005](0005-hinge-mechanism.md) must assume this.
- **The 15 mm is earned entirely here.** An earlier draft had
  [ADR-0006](0006-rear-edge-io-vs-hinge.md) sharing the cost as an I/O shelf;
  that ADR has since been rejected, its premise having been a misread photograph.
  The worst mass case needs 14.6 mm on balance grounds alone, so nothing changes.
- There is now a design rule worth following through detail design:
  **hollow the lid, leave the base solid.** Dead material in the lid is the worst
  place for mass in this device; the same material in the base is free ballast.
- The 15 mm tail sits directly behind the keyboard's rear I/O edge, which is
  useful for [ADR-0006](0006-rear-edge-io-vs-hinge.md): it is somewhere to route
  a port or place a switch paddle.
- **The ballast pocket was dropped when the geometry was built.** It was carried
  as insurance against a mass *bracket*; that bracket has since been replaced by
  masses measured off the model, and the margins pass on the pessimistic printed
  estimate. Hosting a pocket would mean thickening the base's front wall by about
  6 mm, because the keyboard fills the base almost edge to edge and there is no
  free volume. If the built device ever needs ballast, a steel strip tapes to the
  **underside of the base at the front, between the feet** — free in closed
  height, since the front is the thin end of the wedge.
- **The rear feet, not the tail's rear edge, set the tipping contact line.** This
  is easy to lose: the whole analysis measures the setback from where the device
  touches the desk. A 10 mm foot pad placed 1 mm in from the tail edge gives an
  effective setback of 14.0 rather than 15.0 — margin 1.113 instead of 1.149.
  Moving the feet just 5 mm further inboard gives 9.0 and **the device tips**
  (margin 0.934). `cad/build.py` now computes the margin from the actual foot
  position.
- Before the ballast pocket is sized, the first printed lid and base must be
  weighed and their balance points found on a knife edge. Until then, the pocket
  is drawn at the maximum plausible size (30 g of steel) and can only shrink.
- Lap use is out of scope for this ADR; nothing here helps it.

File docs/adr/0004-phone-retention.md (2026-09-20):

# ADR-0004: How the phone is held in the lid

- **Status:** Accepted
- **Date:** 2026-09-20
- **Decides:** F1, F6, F7; contributes 1.2-1.5 mm to N1 and ~25 g to the
  [balance problem](../analysis/balance.md)

## Context

The lid is ~197 x 90; the phone is 160.1 x 76.1 x 8.2 and sits in it in
landscape, leaving ~18 mm of margin on each side and ~7 mm front and rear.

The phone's camera bump takes the envelope to 9.4 mm over part of the rear face.
Its fingerprint reader is on the rear, upper third — reachable only if the rear
is open. Its USB-C is on a short edge, which in landscape points sideways, so
charging access (F6) is easy in every option here.

This decision is doubly weighted: the lid skin is 1.2 mm of the closed stack
*and* ~25 g of lid mass, and lid mass is the thing that tips the device over. The
lighter option is also the thinner option and the more stable one.

## Options

### Option A — closed pocket (chosen)

A tray with a full rear wall; the phone drops in and is captured by a lip on the
front face. Cutouts for the camera, fingerprint reader and USB-C.

| Pros | Cons |
|---|---|
| Phone's rear is fully protected | +1.2 mm closed height, +25 g lid mass |
| Stiffest lid for the least material, no rib scheme needed | Fingerprint reader is covered — decisive, and the reason this option was previously discounted |
| Cleanest exterior | Heat from the phone has nowhere to go |
| Simple to model and print flat | Tool-free removal needs a deliberate push-out feature |
| Camera bump passes through a cutout; the wall does not thicken | |

### Option B — open bezel frame

A perimeter frame with lips that grip the phone's front face; the phone's own
rear is the outer surface of the closed device.

| Pros | Cons |
|---|---|
| Thinnest and lightest: 0 mm of skin, ~15 g | Zero rear protection — the phone's glass back faces the world |
| Camera bump protrudes into free air, needs no pocket | Frame must grip the front bezel, which intrudes on screen edges |
| Fingerprint reader and rear fully accessible | Least stiff; a 197 x 90 open frame in PETG will flex |
| Best case in the balance analysis | Phone retention relies entirely on lip engagement and friction |
| Phone dissipates heat normally | |

### Option C — frame plus removable rear cover

Model B, and additionally a snap-on rear panel that can be fitted or left off.

| Pros | Cons |
|---|---|
| The user picks thin-and-exposed or thick-and-protected, per outing | Two parts to design, two to keep aligned, one to lose |
| The frame can be stiffened by the cover when fitted | The frame must be stiff enough to work *without* the cover anyway, so the weight saving is smaller than in B |
| Good fallback if B turns out too flexible | Most CAD work of the three |

### Option D — frame with a skeletal rear brace

A frame as in B, plus a diagonal or X-shaped rib across the rear that stiffens
the lid without closing it, routed to clear the camera bump and the fingerprint
reader.

| Pros | Cons |
|---|---|
| Recovers most of B's lost stiffness for ~5 g and 0 mm of added stack (the rib sits over the phone's rear, outside the closed stack) | Rib is the outermost surface and takes every scratch |
| Keeps the fingerprint reader usable | Looks deliberate or looks unfinished, depending on execution |
| Gives somewhere to mount the hinge leaves properly | Needs care to avoid pressing on the camera bump |

## Decision

**Option A — closed pocket with a full rear wall.**

The fingerprint reader is the main function a closed back gives up, and it will
not be used. With that objection removed, the remaining trade is 1.2 mm against
full rear protection for the phone, a stiff lid that needs no rib scheme, and a
clean exterior — and the owner's call is that the protection is worth it.

Closed height becomes **22.24 mm** at the rear, 18.26 at the front.

Note this is 0.40 better than the 22.44 quoted while this ADR was open: that
figure carried a 0.50 air gap between keycaps and screen, which was an artifact
of how the scenario was first written. A closed-back lid takes the same 0.30
felt liner as an open frame — there is no reason for the gap to differ.

## Consequences

### Thickness

- **Every thickness lever in the project is now spent.** 22.24 mm is the design
  point and there is no remaining way to reduce it without reopening
  [ADR-0002](0002-keyboard-integration-depth.md) or
  [ADR-0008](0008-base-floor.md).
- The one refinement still available is ADR-0008 Option E — a 0.8 ribbed floor
  sitting in the keyboard's rim recess — which would give **21.84 mm**. It is
  now worth pursuing rather than optional, because of the margin problem below.
- **N1's hard limit of 22.5 is now binding, with 0.26 mm of margin.** The
  sensitivity note in the [thickness budget](../analysis/thickness-budget.md)
  says that if coupon 2.4 shows the base flexes under typing, the floor goes to
  2.0-2.5 — which would put the device at 23.0-23.5 and break the limit. There
  is no headroom left to absorb that. The limit itself should be restated with a
  real rationale, since 22.5 was derived from an early estimate of this very
  scenario and is self-referential.

### Balance

- The lid gains ~25 g, so `M_lid` goes from 182 to 207 and the bare device tips
  at 127 deg rather than 133.
- That, compounded by the shell masses turning out roughly double the original
  estimates, is what drove [ADR-0003](0003-lid-balance-strategy.md) to a **15 mm**
  rear setback rather than 11. See [balance.md](../analysis/balance.md).
- A design rule follows for this part specifically: **hollow the lid wherever it
  carries no load.** The 18 mm-wide solid rings down each side are dead mass in
  the worst possible place, and removing them moves the balance directly.

### Phone orientation — determined, not chosen

Screen rotation is a software matter. The hardware constraint is that the **power
and volume buttons must end up on the top edge and stay reachable**, which fixes
the orientation rather than leaving it open.

On the Pixel 3a XL, power and volume are both on the right-hand edge in portrait.
Rotating the phone 90 deg counter-clockwise to bring that edge upward puts:

| Phone edge | Lands on | Needs |
|---|---|---|
| Right — power, volume | Lid's top long edge, away from the hinge | Cutouts or relief |
| Bottom — USB-C | Lid's **right** short edge | Cutout, required by F6 |
| Top — 3.5 mm jack | Lid's left short edge | **Nothing — no cutout.** Decided; the jack is not used |
| Left — SIM tray | Lid's bottom long edge, at the hinge | Nothing; inaccessible and unimportant |

This is the same orientation Mk2 used, which is visible in
`../palmtop_mk2/maker_world/palmtop.jpg` — the earpiece and front camera sit on
the left of the landscape screen, meaning the portrait top points left.

**Accidental button presses: not a problem in practice.** The lid's top edge is
both where the buttons are and where a hand grips to open the clamshell, which
looks like it should cause trouble. Mk2 used the same phone in the same
orientation and did not, over its whole service life. That is field evidence from
the predecessor and it outranks reasoning from the geometry.

One difference is worth a glance before assuming it transfers: Mk2's lid was an
open frame, and in `../palmtop_mk2/maker_world/full_opened.jpg` its top edge
appears to be relieved in the middle, with printed material only at the corners.
Mk3's closed pocket will have a continuous wall along that edge instead. If that
relief is *why* fingers stayed off the buttons, the change matters; if the reason
is simply that the grip naturally falls on the base, it does not. Worth thirty
seconds with the physical Mk2 rather than a guess from a photograph.

Pressing the buttons themselves is not a tipping concern: the force is directed
down the lid toward the hinge, not perpendicular to the screen. Tapping the
*screen* is the tipping case, and it is already in the acceptance criteria.

### Where the phone sits in the lid, and the button window

The phone is **biased forward**, not centred: 4.00 mm of wall on the button edge,
9.35 mm on the hinge side. Centred would put 6.68 mm in front of the buttons,
which is not an opening but a shaft — a phone case manages with about 1.5.

Mk2 solved this the same way, and its STL was measured rather than guessed:
4.70 front, 9.60 rear, with **one 54.0 x 10.0 window spanning both buttons**
instead of two holes. Mk3 uses 4.00 rather than 4.70 because Mk2's full-width
hinge barrel needed no station reliefs and Mk3's stations do — the bias buys the
material between the phone pocket and the relief, which went from 0.97 mm to
3.65 mm.

Both lids centre the same phone in X in the same orientation, so Mk2's window
span transfers directly: **X -48.6 to +5.0**. Task 0.10 is superseded.

The bias costs balance: it moves `r_lid` from 45.03 to 47.05 and the tipping
margin at 180 deg from 1.225 to about 1.17. The lightening work that N4 requires
anyway more than repays it, but the two must be done in that order.

### The phone is taped in, not gripped

Mk2 held its phone with double-sided tape and no retention lips at all, and that
carries over. The pocket is therefore a plain recess the depth of the phone, with
nothing overlapping the screen — which is what this model already had, so no
geometry changed and **task 0.8 (front bezel width) is superseded**.

**The tape goes on the pocket's side walls, not its floor.** On the floor, a 1 mm
tape adds its full thickness to the closed stack: 22.24 becomes 23.24, which is
0.74 over N1's hard limit and more than every millimetre the project fought for
elsewhere — the lid's back skin was worth 1.2, ADR-0008 Option E is worth 0.4.
Recessing pads into the 1.2 mm rear wall does not help either; a 1 mm recess
leaves 0.2 mm, which is a hole.

On the side walls it costs nothing but pocket width. The pocket widens from 160.7
to 162.7 and the side blocks narrow from 18.05 to 17.05; closed height is
unchanged.

Adhesion is nowhere near the constraint. Holding an inverted phone is 1.64 N
against roughly 1250 mm2 of contact on the two short ends alone, and the pocket
already captures the phone on all four sides — the tape only has to stop it
falling out.

### Detail design

- The camera cutout is a **through-hole in the rear wall**, 11.2 x 23.2, again
  taken from Mk2's STL and referenced to the phone's edges. Because it goes
  through, the bump's height never mattered and task 0.6 is superseded — a bump
  taller than the 1.2 wall simply protrudes, as it does on the naked phone.
- A USB-C cutout on the short edge is still required by F6.
- The phone's rear is fully covered, so it sheds heat only through the screen.
  The Pixel 3a XL is not a hot device, but sustained use in a sealed pocket is
  worth watching during Phase 4.
- **Unlocking is PIN or password only.** Recorded as an accepted consequence, not
  an objection — it follows directly from the reason this option was chosen.
- **F7 has been relaxed rather than met.** With the phone taped in, removal means
  prying, not a thumb push. Mk2 lived with this for its whole service life, so it
  is an accepted trade — but it is a trade, and it should not be rediscovered as
  a defect two iterations from now.
- The 53.6 mm button window gives somewhere to get a tool in when the phone does
  have to come out.

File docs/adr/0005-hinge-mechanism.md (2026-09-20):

# ADR-0005: Hinge mechanism

- **Status:** Proposed
- **Date:** 2026-09-20
- **Decides:** F3, F8; sets the rear-edge geometry that ADR-0003 and ADR-0006
  both depend on

## Context

The hinge must hold the lid at any angle hands-free (F3). From
[balance.md](../analysis/balance.md), the torque needed at 90 deg is

```
M_lid * g * r_lid  =  0.207 kg * 9.81 * 0.045 m  =  0.091 N*m  =  0.93 kgf*cm
```

**That is a very small number, and it is the single most important fact in this
ADR.** For calibration: Reell's RT-50 is a deliberately scaled-down 5 mm series
marketed for consumer electronics and mobile devices, and its range *starts* at
0.11 N*m — the smallest industrial hinge built for this class of application
already exceeds what this entire device needs. Mk3 sits below the bottom of the
commercial range.

The hinge sits on the rear edge, which per
[ADR-0006](0006-rear-edge-io-vs-hinge.md) also carries the keyboard's switch,
LEDs and USB-C, and per [ADR-0003](0003-lid-balance-strategy.md) its axis is
~15 mm forward of the base's rear edge rather than at the corner.

Mk2 used a printed barrel with a rod. On the side photo that barrel protrudes
beyond the body outline.

### Where the axis sits

Not on the parting plane, as earlier drafts assumed, but at the **lid's
mid-thickness, z = 17.54**. Two independent collisions forced this, both found by
building the geometry and sweeping it through its opening range rather than by
reasoning about the closed position. They are worked out in
[clamshell-geometry.md](../analysis/clamshell-geometry.md); the consequences for
this ADR are:

- Knuckle OD is capped by the lid's thickness at the axis, not by load. **9.0 mm**
  fits inside 12.84-22.24 with margin.
- The base's knuckles are **posts rising out of the tail**, not bosses on the
  parting plane, and they must approach the axis from directly underneath.
  Nothing may stand behind the axis above 12.84, or the lid hits it at 180 deg.
- Each station needs a **relief in the lid of radius 5.70** — larger than the
  lid's own rear radius of 4.70 — or the post has no cross-section to exist in.

### A correction to an earlier claim

Earlier drafts of this ADR asserted that a printed barrel's diameter "adds
directly to the closed height at the thickest edge". That is true only of an
**outboard** barrel wrapped around the outside of the parting line — which is how
Mk2 did it, and why it looks the way it does.

An **inboard** axis sitting on the parting plane costs nothing. The parting plane
here is at floor 1.2 + keyboard 9.52 + keycaps 1.82 = **12.54 mm**, inside a
22.24 mm envelope, so even a 10 mm barrel centred there fits with room above and
below. What an inboard axis costs instead is opening angle — the two bodies
collide sooner — which is a geometry problem, not a thickness penalty. It is
worked out in [clamshell-geometry.md](../analysis/clamshell-geometry.md), and the
answer is that the lid ends at the axis rather than overhanging it. The rest of
this ADR assumes the corrected version.

## Options

### Option A — printed knuckles, bolted stations, elastomer sets the force (recommended)

Three or four discrete hinge stations spread across the 193 mm rear edge.
Interleaved knuckles printed into both halves, each station closed by an M3 bolt
and nut. Friction is **axial**: the bolt squeezes the knuckle end faces together.
A compliant element in each stack — an O-ring, a TPU washer or a wave washer —
carries the clamp load.

#### The governing principle

**The bolt sets deflection; the elastomer sets force.**

A bolt clamping rigid PETG against rigid PETG sets force by tightening torque,
which cannot be judged by feel at this scale and which the plastic then sheds by
creeping. A bolt compressing an elastomer sets force by *how far it is
compressed*, which is repeatable ("half a turn"), tunable after assembly, and
survives creep — the plastic's relaxation consumes a small fraction of the
elastomer's travel instead of all of the clamp load.

This is why the reference designs carry a soft core rather than relying on the
fit itself.

#### The torque is not close to being a constraint

Friction on an annular knuckle face of Ø14 outer / Ø3.5 inner has an effective
radius

```
r_eff = (2/3) * (r_o^3 - r_i^3) / (r_o^2 - r_i^2) = 4.9 mm
```

With PETG on PETG (`mu` ~ 0.35), three stations contributing two sliding
interfaces each:

```
N = 0.091 / (6 * 0.35 * 0.0049) = 8.8 N of axial force per station
```

(That `r_eff` was computed for a 14 mm knuckle. At the 9.0 mm the packaging
actually allows, `r_eff` is 2.7 and the clamp becomes 16 N per station — still
barely finger-tight, and still far below what the elastomer can deliver.)

**8.8 N on an M3 bolt is barely finger-tight.** As with every other load in this
project, the requirement sits far below what the mechanism can deliver. The
design problem is making the friction *low and repeatable*, not high — which is
exactly what the compliant element is for.

The radial alternative — O-rings gripping a full-width rod — was evaluated and
reaches the same conclusion by a different route: at a Ø8 rod and 80 mm of total
sleeve length the contact pressure works out to 0.019 MPa, roughly 2% of an
O-ring's ordinary sealing duty, or about 26x headroom. Either mechanism works.
The bolted version is preferred for the reasons below.

| Pros | Cons |
|---|---|
| Torque requirement met with enormous margin by either mechanism | Actual torque unknown until a coupon is printed and measured |
| **Adjustable with a screwdriver after assembly** — the single best property here, and one no purchased hinge has | Adds bolts, nuts and compliant washers to the BOM |
| Compliant element makes the setting survive PETG creep | The wear mode is real, just slow; patent literature calls out the lack of wear compensation as the classic weakness |
| Friction elements are consumables: a worn washer costs pennies | Several stations must be co-linear, though far less precisely than a rod demands |
| **Zero lead time** — unblocks the rear-edge cross-section immediately | |
| Discrete stations leave gaps between them for ADR-0006's port tunnels | |
| Tolerant of print warp — see below | |

#### Why stations rather than one full-width rod

An earlier draft of this ADR specified a single steel rod through a continuous
full-width barrel, on the argument that continuity resists racking on a 197 mm
lid. Two things were wrong with it.

**Racking resistance comes from the span between the outermost engagement points,
not from continuity.** Three or four stations spread across 193 mm resist racking
nearly as well as a continuous barrel, and far better than two purchased pods
clustered at the ends.

**A 193 mm continuous knuckle array is a manufacturing problem.** It requires
both printed parts to be straight and co-axial to a fraction of a millimetre over
193 mm. A PETG part that size will bow — 0.3-0.5 mm is realistic — leaving a
choice between a rod that binds and clearance that is slop. Discrete stations
self-align individually and are indifferent to bow between them.

A full-width rod remains the fallback if coupon 2.2 shows unacceptable racking.

### Option B — purchased mini torque hinges (upgrade path)

Two small friction hinges pocketed into base and lid, fixed with screws into
heat-set inserts.

| Pros | Cons |
|---|---|
| Known, specified torque and cycle life | **Longest lead time on the critical path**; blocks the cross-section until in hand |
| Thin leaves, typically 1-2 mm | Pods only — much weaker against racking on a 197 mm lid |
| Torque does not fade the way an interference fit does | Pocket geometry is dictated by whatever part actually arrives |
| No consumables | Metal in thin printed walls concentrates stress at pocket corners |
| | Two pockets must align precisely or the lid racks |

Sourcing spec, if this route is taken:

| Filter | Value |
|---|---|
| Torque, **total across all hinges** | 1-2 kgf*cm (0.10-0.20 N*m) |
| Count | 2, for anti-racking rather than for torque |
| Leaf thickness | <= 1.5 mm |
| Barrel diameter | <= 6 mm |
| Range | 0-180 deg |

Search terms: *torque hinge*, *friction hinge*, *position control hinge*. In
Russian, *петля с трением* / *фрикционная петля*.

Avoid: "soft close" and "damping" hinges (one-way dampers, they do not hold
position), spring-loaded or self-closing types, furniture hinges, and any listing
that does not state a torque figure. **Do not over-specify** — the common
"2 pcs, 3 kgf*cm" listing is six times the requirement; it will be stiff to open
and the moment will pull heat-set inserts out of PETG.

Salvaging hinges from a dead laptop screen is the same part for free, at the cost
of a chassis-specific leaf shape.

### Option C — printed barrel with an interference fit only (Mk2's approach)

| Pros | Cons |
|---|---|
| No purchased parts beyond the rod; proven to work on Mk2 | Friction comes from PETG pressed against PETG, which creeps under sustained load and goes loose |
| Full-width barrel is very stiff | No way to re-tension without reprinting |
| | This is the failure mode Option A exists to avoid |

### Option D — printed pods at the ends

Option A or C, but as two short barrels, leaving the middle of the rear edge
clear.

| Pros | Cons |
|---|---|
| Frees the rear centre, if ADR-0006 needs it | Short barrels are much weaker against racking |
| | Option A's full-width barrel solves ADR-0006 a better way — see below |

### Option G — Option A, but with the knuckles as separate bolted parts

The knuckle blocks are printed as their own small parts and bolted to the base
and lid, rather than being printed integral with them.

This exists because of a conflict inside Option A that has no solution while the
knuckles are integral. The base is 197 x 105 and realistically prints floor-down;
any other orientation puts overhangs everywhere. But printed floor-down, the
knuckles rise from the rear rim with their bores horizontal, which means **the
layer lines run across the bending load the knuckles carry.** That is the weak
direction, and it is the one direction the lid's whole weight acts in.

| Pros | Cons |
|---|---|
| Each knuckle block prints in its own optimal orientation, with layers along the load rather than across it | More parts, more fasteners, more assembly |
| The hinge becomes replaceable and re-positionable without reprinting a 197 mm part | Two bolted interfaces per station instead of one — more places for play to accumulate |
| Bores print vertically, so no teardrop compensation and no support | Blocks must locate precisely against each other or the lid racks; needs dowels or a keyed seat |
| Lets the knuckle be a denser, more solid part than a shell wall can be | Adds height at the interface unless the blocks seat into pockets |
| A damaged knuckle is a small reprint, not a scrapped base | |

### Option E — flexure / living hinge

| Pros | Cons |
|---|---|
| Thinnest possible | No position holding at all; fails F3 outright |
| No moving parts | Poor fatigue life in PETG |

### Option F — magnetic mount with discrete angle slots

| Pros | Cons |
|---|---|
| Thin, simple, no friction to wear | Not a clamshell; the lid becomes a losable separate object |
| The slot sets the angle, which helps ADR-0003 | Discrete angles only |

## Decision

Not yet made. **Option A is the recommendation**, with Option B as a defined
upgrade path rather than a fallback.

Three reasons, in ascending order of weight:

1. **The torque requirement is trivially met.** 26x headroom on a first-pass
   calculation is not a close call, and the low working stress puts the elastomer
   in the regime where it degrades slowest.
2. **It can be spread across the full width.** A 197 mm lid on two small pods
   clustered at the ends will rack. Three or four stations spanning 193 mm will
   not — and unlike a continuous barrel, they tolerate the bow a PETG part that
   size will have.
3. **It has no lead time.** Hinge sourcing is currently the longest item on the
   critical path and it blocks the rear-edge cross-section, which is where three
   open ADRs converge. Option A unblocks all of it today.

Whether the knuckles are integral or separate bolted blocks (Option G) is a
sub-decision inside this one, and it turns on print orientation rather than on
mechanics. Coupon 2.2 should print the knuckle section both ways and load it to
failure; the answer is whichever survives.

This reverses an earlier recommendation in favour of purchased hinges. That
recommendation rested on "printed friction degrades", which is a fair objection
to Option C and not to Option A — the mechanism is different, and the numbers
were never checked.

### What closes this ADR

Coupon 2.2: a printed two-station knuckle section with bolts and compliant
washers, torque measured with a spring scale at a known radius, then 100
open/close cycles and measured again. Print the knuckles both integral and as
separate blocks (Option G) and load both to failure, since the choice between
them is a print-orientation question that no amount of reasoning settles.
Accept Option A if the torque lands between 1x and 3x of 0.091 N*m and loses less
than 30% over the cycles. Otherwise fall back to Option B.

## Consequences

- **Hinge sourcing comes off the critical path.** M3 bolts, nuts, O-rings and
  wave washers are stock items. [plan.md](../plan.md) is updated accordingly.
- **Station placement is free.** [ADR-0006](0006-rear-edge-io-vs-hinge.md) has
  been rejected — the USB-C is on the keyboard's side face, not the rear edge —
  so nothing competes for that edge. Stations sit at **-88, 0, +88**, chosen
  purely for anti-racking span: 176.0 mm against a 178.6 mm ideal.
- Discrete stations were originally chosen partly to leave gaps for port tunnels.
  That reason evaporated; the print-orientation and warp reasons did not, and
  they are sufficient on their own.
- Station count and spacing are a racking question, not a torque one: place the
  outermost stations as far apart as the rear edge allows, and add a middle one
  for knuckle support rather than for friction.
- **Knuckle print orientation conflicts with printing the base as one part.**
  Floor-down is the only sane orientation for a 197 x 105 base, and it puts the
  knuckle layers across the load. Option G above is the way out; if the knuckles
  stay integral, they need to be thickened to compensate for working across
  layers, and that thickening has to fit inside the 15 mm section.
- **The base's rear pocket wall takes the hinge's point loads.** It is 12.54 mm
  tall at ~1.6 mm thick. The tail braces it from behind, so it is a channel
  rather than a free-standing wall, but local gussets under each station are
  likely needed and should be in the coupon.
- Nuts want capture pockets, not free nuts — a hex pocket in the knuckle, or
  heat-set inserts if the geometry allows. A nut that spins is a hinge that
  cannot be adjusted.
- F8 (stays shut) turns out to be solved by this ADR after all, and is written up
  as [ADR-0009](0009-closure-retention.md): holding the lid shut while inverted
  needs the same 0.091 N*m as holding it at 90 deg, so the torque specified here
  covers it. Coupon 2.2's post-cycle figure therefore decides F8 as well as F3.
- A hard stop for the maximum opening angle is easier as printed geometry in the
  knuckles than as a purchased hinge's own stop. Relevant if
  [ADR-0003](0003-lid-balance-strategy.md) Option C is ever revisited.
- Buy a range of compliant elements at once — O-rings in several cross-sections,
  TPU washers, M3 wave washers — so coupon 2.2 tunes by swapping rather than
  reordering. They are pennies.
- Adjustability is the property to protect through detail design. If the bolt
  heads end up buried where a screwdriver cannot reach once assembled, the main
  advantage of this option is lost.

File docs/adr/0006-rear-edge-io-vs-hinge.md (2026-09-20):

# ADR-0006: Keyboard I/O on the hinge edge

- **Status:** Rejected — the premise was a misreading
- **Date:** 2026-09-20
- **Decides:** nothing. F5 turned out not to be contested.

> **This ADR addressed a conflict that does not exist.** The keyboard's USB-C is
> on its **right side face**, not on the rear edge. It is kept rather than
> deleted because the reasoning it drove — discrete hinge stations, the I/O
> shelf idea, the height analysis — shaped ADR-0005 and is worth being able to
> re-read. See *What actually happened* at the end.

## Context

The keyboard carries **all** of its I/O on one long edge: an OFF/ON slide switch,
four status LEDs (charge, caps lock, two wireless) and the USB-C charging port.
See `reference/photos/keyboard-rear-edge-switch-leds.jpg` and
`reference/photos/keyboard-rear-edge-usb-c.jpg`.

Two things then dissolved this, one after the other.

**First**, the owner's decision: the power switch stays permanently ON and the
LEDs are not needed. F5 was relaxed, leaving one feature — the USB-C port.

**Second**, and fatally: **the USB-C is not on the rear edge at all.** It is on
the keyboard's right side face. The premise above is simply wrong — the two
photographs show two different edges, and the second was read as the first seen
at an angle.

That edge is also the **thick** edge of the 2.64 deg wedge (9.52 vs 5.54), and
the wedge rises front-to-rear, so the I/O edge is the rear edge — which is
exactly where the hinge goes.

This looked like a genuine conflict: the hinge wants the full width of the rear
edge for stiffness, the I/O wants the same width to stay reachable, and F5
requires the I/O to work without disassembly.

[ADR-0005](0005-hinge-mechanism.md) has since made it much less sharp. The two
can occupy the same width at **different heights**: the keyboard's rear face is
9.52 mm tall, while the hinge axis sits naturally on the parting plane at
~12.5 mm — above it. A full-width barrel runs over the keyboard, and the port
tunnels run underneath it through the 15 mm tail. What remains is a
cross-section problem rather than a contest for the same space.

## What actually happened

The keyboard's rear edge carries the switch and the LEDs, neither of which needs
access. The USB-C is on the **right side face**, 8 mm back from the rear edge,
its opening 3.94 mm tall centred at Z 6.17.

So the rear edge carries nothing that needs a hole, and the hinge has all
193 mm of it. The consequences:

| | Under the misreading | Actually |
|---|---|---|
| Rear-edge features needing access | 1 (thought: 6) | **0** |
| Hinge station placement | right one pushed inboard to +70 | **symmetric, ±88** |
| Span between outermost stations | 159.3 mm, 10.8% short | **176.0 mm, 1.5% short** |
| USB-C tunnel | a funnel through 15 mm of tail | a hole through 1.9 mm of side wall |
| Risk R1 | live, quantified | **gone** |

The 15 mm rear setback stands unchanged, but it is now earned entirely by
[ADR-0003](0003-lid-balance-strategy.md) — the worst mass case needs 14.6 mm on
its own. This ADR was never really paying for any of it.

## What survives

Not nothing. Two decisions made under the wrong premise turned out to be right
for other reasons and are kept:

- **Discrete hinge stations** rather than a continuous full-width barrel
  ([ADR-0005](0005-hinge-mechanism.md)). Chosen here to leave gaps for port
  tunnels; kept because a 193 mm continuous knuckle array demands a straightness
  no PETG part that size will hold.
- **The height analysis of the rear edge**, which fed directly into discovering
  that the hinge axis cannot sit on the parting plane at all.

## Lesson for the record

The measurement that would have caught this cost nothing and was never asked
for: *which face is the port on*. Tasks 0.1 and 0.1b both asked how far along an
edge and how high up, and neither asked which edge. A datum is not a datum until
it names the surface.

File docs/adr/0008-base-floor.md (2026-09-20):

# ADR-0008: Base floor

- **Status:** Accepted
- **Date:** 2026-09-20
- **Decides:** F2, and 1.2 mm of N1

## Context

[ADR-0002](0002-keyboard-integration-depth.md) fixed the keyboard as a sealed
9.52 mm block, leaving exactly two levers on closed thickness: the lid's back
skin ([ADR-0004](0004-phone-retention.md)) and the base's floor, this ADR. Each
is worth 1.2 mm.

The floor is optional in a way the lid's back is not. The keyboard's own bottom
shell is already flat, already stiffened by a 1.68-wide perimeter rim, and
already designed to be the underside of a device — it could simply *be* the
bottom of the base, the way the phone's back could be the top of the lid.

Two useful measurements from [measurements.md](../measurements.md):

- The keyboard's bottom face is **recessed inside its perimeter rim by a little
  under 1 mm**. Anything thinner than that recess, sitting within the rim
  footprint, adds zero to the closed height.
- The base is 197 x 90; an unsupported floor spans the full key field, which is
  where typing force lands.

The floor also carries ~26 g of mass at the base, which matters to
[ADR-0003](0003-lid-balance-strategy.md): removing it moves the tipping point
from 133 deg of opening to 124 deg.

## Options

### Option A — full floor, 1.2 mm (chosen)

A conventional pan. The keyboard drops in and sits on it.

| Pros | Cons |
|---|---|
| Keyboard's underside is protected and enclosed | +1.2 mm closed height: 21.04 instead of 19.84 |
| Stiff base with no additional mechanism to design | Misses the N1 target of 20.0, though inside the 22.5 hard limit |
| +26 g at the base, which improves stability directly | ~26 g against the 400 g budget (N4) |
| Feet mount on printed geometry, not on the keyboard | Encloses the keyboard's own vents, if it has any |
| Keyboard needs no retention mechanism beyond a lip or friction | |
| Dust and debris stay out of the base cavity | |
| Keyboard remains trivially removable for Mk4 | |

### Option B — no floor, retaining straps in the rim recess

Two or three straps ~0.8 thick spanning the underside within the sub-1 mm
recess, so they cost nothing in height.

| Pros | Cons |
|---|---|
| 19.84 mm, meets the N1 target | Depends on the recess being uniform; measured at one point only |
| Zero height cost for the straps themselves | Straps are unsupported spans and the likely failure point |
| | Device rests on the keyboard's own shell; feet load it directly |
| | Removes 26 g from the base, costing 9 deg of tipping margin |

### Option C — no floor, keyboard bonded to the frame

| Pros | Cons |
|---|---|
| Thinnest and simplest | Semi-permanent; contradicts ADR-0002's reason for keeping the keyboard intact |
| Stiffens the frame considerably | Adhesive creep in a warm bag |

### Option D — partial floor: solid at the front, straps at the rear

The front of the closed stack has 3.98 mm of headroom relative to the rear
(15.86 vs 19.84), so a floor under the front costs nothing at the governing
section.

| Pros | Cons |
|---|---|
| Free at the governing section | Two retention mechanisms in one part |
| Solid anchor for the ADR-0003 ballast pocket, which is at the front anyway | The rear still needs straps, so Option B's risk is not eliminated |
| 19.84 mm | Rear of the keyboard — the heavy, battery-bearing end — is the unsupported one |

### Option E — thin floor with ribs into the rim recess

A 0.8 floor with 0.6-tall ribs on its **upper** face, sitting inside the
keyboard's bottom recess. Effective structural depth 1.4 mm for 0.8 mm of height.

| Pros | Cons |
|---|---|
| 20.64 mm — recovers 0.4 of Option A's 1.2 | Same dependency on recess uniformity as Option B |
| Stiffer than a flat 1.2 floor, not weaker | A 0.8 floor feels flexible in hand before the keyboard is in |
| Keeps every benefit of a full floor: enclosure, feet, mass, removability | Ribs must clear whatever is on the keyboard's underside (labels, pads) |
| Ribs give the keyboard defined bearing points rather than a floppy plane | More print-orientation sensitivity |

## Decision

**Option A — a full 1.2 mm floor.** Closed height becomes **21.04 mm** at the
rear, 17.06 at the front.

This is the owner's call rather than a conclusion from the analysis: 21 mm is
acceptable, and an enclosed base is worth the millimetre. It is also the option
that needs no new mechanism, keeps the keyboard removable for Mk4 without
depending on an unverified recess dimension, and makes the balance problem easier
rather than harder.

**Option E stays open as a refinement**, and has since become the more important
half of this decision. It preserves every property of Option A, gives back
0.4 mm, and is *stiffer* than the flat 1.2 floor rather than weaker. With
[ADR-0004](0004-phone-retention.md) having spent the lid's skin as well, it is
the only reduction left anywhere in Mk3. Resolve it with task 0.4 and coupon 2.4,
early.

## Consequences

- Closed height is 21.04 mm, over the N1 target of 20.0 and inside the 22.5 hard
  limit. **N1's target is not met, by 1.04 mm, by choice.** Recorded rather than
  quietly redefined.
- The lid's back skin became the only remaining thickness lever.
  [ADR-0004](0004-phone-retention.md) has since spent it too, on rear protection
  for the phone, putting the device at **22.24 mm**. Option E below is now the
  only reduction left in the project, and the 0.26 mm of margin against N1's hard
  limit makes it worth pursuing rather than optional.
- Base mass returns to ~137 g, worth nine degrees of tipping margin. ADR-0004
  then added 25 g to the *lid*, which took most of that back: the device tips at
  127 deg, and the rear setback goes to 15 mm to eliminate tipping outright. See
  [balance.md](../analysis/balance.md).
- Task 0.4 (recess depth around the perimeter) was expected to drop off the
  critical path. It has not: it gates Option E, which is now the project's only
  remaining way to reduce thickness.
- **Keyboard retention turned out to need nothing at all.** The pocket captures
  the keyboard on all four sides with 0.30 of clearance, and when the device is
  shut the lid is 0.30 above the keycaps — so the keyboard cannot lift out.
  Closed and inverted, it stays; open and inverted is not a use case. The
  fallback, if it rattles, is a compliant strip in the pocket floor or tape on
  the pocket's side walls, the same trick the phone uses; tape on the floor would
  cost its own thickness in closed height and must be avoided.

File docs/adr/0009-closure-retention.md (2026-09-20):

# ADR-0009: Keeping the device shut when closed

- **Status:** Proposed
- **Date:** 2026-09-20
- **Decides:** F8

## Context

F8 requires the device to stay shut when closed. It has been referenced in
[ADR-0005](0005-hinge-mechanism.md) as "a separate small decision" since the
project started and has never had an owner.

The load case is not the closed device sitting on a desk — there gravity holds
the lid down. It is the device **inverted or on edge in a bag**, where the lid's
weight tries to swing it open.

That load turns out to be a number already computed. From
[balance.md](../analysis/balance.md), the torque needed to hold the lid at
90 deg is

```
M_lid * g * r_lid  =  0.207 * 9.81 * 0.045  =  0.091 N*m
```

Inverted and closed, the lid is again horizontal with its centre of mass 45 mm
from the axis, so the moment trying to open it is **the same 0.091 N*m**. The
two requirements — hold at 90 deg, and hold shut upside down — are numerically
identical, because the moment arm is the same in both cases.

[ADR-0005](0005-hinge-mechanism.md) targets 1.5-3x that figure. So the hinge, as
already specified, holds the device shut with margin, for free.

What the hinge does *not* cover is shock — a dropped bag, or a bag that squeezes
the device and levers it open.

## Options

### A — hinge friction alone

| Pros | Cons |
|---|---|
| Free; the torque is already required by F3 and already specified with margin | Static only — a shock load exceeds it |
| No parts, no geometry, nothing to fail | Torque fades with wear, and F8 fades with it |
| Nothing to align | No tactile "shut" feedback |

### B — magnets

Neodymium discs in the lid's front lip and the base's front wall.

| Pros | Cons |
|---|---|
| Positive closure with a satisfying snap | **The phone sits in the lid.** A magnetometer is used for the compass and by some apps; magnets near it need checking |
| Handles shock loads | Adds mass to the lid, which is the worst place for it (ADR-0003) |
| Tunable by magnet count and spacing | Pockets and glue, and a magnet that comes loose inside the case is a problem |
| Wears indefinitely | Attracts anything ferrous in a bag |

### C — printed snap lip or detent

An interference feature on the lid's front lip engaging the base's front wall.

| Pros | Cons |
|---|---|
| No parts, no mass | PETG creeps; the snap softens over time, same failure as a printed friction fit |
| Tactile feedback | Needs enough lip to work with — the front of the wedge is only 18.26 mm tall |
| Free once the cross-section exists | Hard to tune after printing |

### D — elastic band or strap

| Pros | Cons |
|---|---|
| Trivially strong, trivially cheap | An extra loose object; the thing people lose |
| Also secures the device against a bag squeezing it | Ugly unless designed in |
| Zero design risk | Manual step every time |

## Decision

Not yet made. **Option A is the recommendation as the baseline**, with B as
insurance if coupon 2.2 shows the hinge torque is marginal or fades badly.

The reasoning: the requirement is already satisfied by a mechanism the design
needs anyway, and the arithmetic showing that is exact rather than approximate.
Adding magnets before knowing whether they are needed would put mass in the lid,
which [ADR-0003](0003-lid-balance-strategy.md) spends real effort keeping out.

Option C is rejected on the same ground as printed friction in ADR-0005: PETG
creeps, and a feature that softens over time is a poor answer to a requirement
about carrying the thing around.

### What closes this ADR

Coupon 2.2 measures hinge torque before and after 100 cycles. If the post-cycle
figure is still above 0.091 N*m with margin, Option A stands and F8 needs no
hardware. If it is marginal, add magnets.

Additionally: a bag test. Carry the assembled device for a week and see whether
it has opened. That is Phase 4, and it is the only test that covers the squeeze
case.

## Consequences

- F8 is coupled to hinge wear. If the hinge loosens over the device's life, the
  device stops staying shut before it stops holding angles — the failure shows up
  in a bag, not on a desk. Worth noting in the Phase 4 checks.
- If magnets are added later, the pockets should be designed in from the start
  even if left empty, because retrofitting them into a finished lid is not
  possible. Same pattern as the ballast pocket in
  [ADR-0003](0003-lid-balance-strategy.md).
- **Check the magnetometer before committing to Option B.** The phone is 8.2 mm
  from where the magnets would sit. Test with a compass app and a loose magnet
  before any geometry is cut.
- Nothing here protects against a bag squeezing the device open. If that turns
  out to matter, Option D is the only reliable answer and can be added at any
  time, since it needs no geometry.

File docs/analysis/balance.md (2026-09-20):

# Balance analysis — will the lid tip the device over backwards?

The concern: the phone (167 g) is heavier than the keyboard (95 g), so the mass
is in the lid, and a clamshell with a heavy lid falls over backwards when opened.

Short answer: **bare, it tips past 127 deg of opening. A 15 mm rear setback makes
tipping impossible across the whole plausible mass bracket, at any angle.**

Both accepted construction decisions moved this number, in opposite directions.
[ADR-0008](../adr/0008-base-floor.md) kept the base floor, adding 26 g to the
base and helping. [ADR-0004](../adr/0004-phone-retention.md) kept the lid's rear
wall, adding 25 g to the lid and hurting slightly more. The net is close to where
it started, and the fix is still free.

## Model

Tipping is a moment balance about the rear ground contact line.

| Symbol | Meaning |
|---|---|
| `M_lid` | mass of lid assembly (phone + lid shell) |
| `M_base` | mass of base assembly (keyboard + base shell) |
| `r_lid` | distance from hinge axis to lid centre of mass, along the lid |
| `d_base` | distance from hinge axis forward to base centre of mass |
| `s` | rear setback: how far the base footprint extends *behind* the hinge axis |
| `theta` | lid lean measured **from vertical**; opening angle = 90 + theta |

Stable while:

```
M_base * (d_base + s)  >=  M_lid * (r_lid * sin(theta) - s)
```

which rearranges to:

```
M_base * d_base  +  s * (M_base + M_lid)  >=  M_lid * r_lid * sin(theta)
```

## Inputs

Footprint assumed 197 (X) x 90 (Y), hinge on the rear edge. Shell masses are
estimated from PETG at 1.27 g/cm3 over the modelled wall thicknesses — these are
the weakest numbers here and must be replaced by weighing the first prints.

| Quantity | Value | Conf |
|---|---|---|
| Phone | 167 g | S |
| Keyboard | 95 g | M |
| Lid shell, closed back | 40 - 83 g | E | see below |
| Base shell, with floor | 42 - 72 g | E | see below |
| `r_lid` | 45 mm (phone centred in a 90-deep lid) | E |
| `d_base` | 41 mm (keyboard mass is rear-biased by battery + wedge) | E |

Three cases, matching the thickness scenarios:

| Case | Construction | `M_lid` | `M_base` |
|---|---|---|---|
| **A** | **floored base, closed-back lid (selected)** | **207 g** | **137 g** |
| B | floored base, frame lid (rejected) | 182 g | 137 g |
| B+ | frame base, frame lid (rejected) | 182 g | 111 g |

## Two corrections to the shell masses

### First: they were estimated far too low

The first run of the parametric model measured the modelled solids and produced
shell masses roughly **twice** the hand estimates this analysis was built on.

The error was in the lid. It was estimated as a thin frame, but the lid is
196.8 wide and the phone only 160.1, so **18 mm of solid material runs down each
side, 8.2 mm thick** — a substantial ring of plastic that the frame model simply
did not count. Same again, smaller, front and rear.

That gives a bracket rather than a guess:

| | Lower bound | Upper bound |
|---|---|---|
| | original hand estimate | massing model, fully solid |
| Lid shell | 40 g | 83 g |
| Base shell | 42 g | 72 g |

The real part sits between, depending on how much of that dead side material gets
hollowed out. Working values of 60 g and 55 g are used below.

**What matters is the ratio, not the absolute masses.** Both halves growing
together barely moves the result; the lid growing while the base does not is what
breaks it.

### Second: those measured masses assume 100% infill

`volume * density` is the solid upper bound, not what comes off a printer. Thin
walls (1.2-1.6 mm) do print essentially solid, but the chunky parts — the lid's
18 mm side spacers, the 15 mm tail — take infill and land near 40%.

Treating solid mass as printed mass had two consequences, both now corrected:

- It produced a spurious **"over the mass budget"** finding. The assembly is
  ~432 g solid but ~374 g as printed, against N4's 400 g. **No lightening work is
  needed**, and a proposal to hollow the lid has been withdrawn.
- It made the tipping margins look better than they are, since the phone and
  keyboard are fixed while only the shells shrink. `cad/build.py` now reports
  both and fails if either tips.

```
                     solid    printed(est)
  lid shell           82.7        52.1 g
  base shell          87.0        60.0 g
  assembly           431.7       374.1 g     N4 budget 400

  margin @150 deg     1.351       1.322
  margin @180 deg     1.170       1.145
```

The printed figures are an estimate. The authoritative number is whatever the
slicer reports, and after that, a scale.

## Sensitivity sweep

Margin is restoring moment over overturning moment; `>= 1.0` means it cannot tip
at that angle. Reproduce with `.venv/bin/python cad/params.py`.

At the decided `s` = 15 mm:

```
  lid  base   @180   @150  s_req   case
   40    42  1.157   1.34   10.8   both light
   83    72  1.165   1.34   10.6   both solid
   60    55  1.156   1.33   10.8   working values
   83    42  1.015   1.17   14.6   heavy lid, light base  <-- worst
   40    72  1.337   1.54    6.6   light lid, heavy base
```

The same sweep at 11 mm put the worst case at 0.878 — tipping at 160 deg — which
is what moved the decision.

Three readings:

1. **At 150 deg — a realistic maximum — every case is comfortable**, by 33% in
   the expected case and 17% in the worst.
2. **At 180 deg every case still clears**, the worst by 1.5%. At 11 mm the worst
   case failed outright, which is the whole reason for the extra 4 mm.
3. **The worst case needs 14.6 mm of setback**, not 11. This is what drove
   ADR-0003 to 15 mm; the sweep below is at the decided value.

There is also a design rule in here, and it runs against the instinct to treat
the two halves alike: **hollow the lid, leave the base solid.** Dead material in
the lid is the single worst place for mass in this device; the same material in
the base is free ballast.

## Result 1 — do nothing (hinge on the rear edge, `s = 0`)

```
sin(theta_tip) = M_base * d_base / (M_lid * r_lid)
```

| Case | `sin(theta)` | `theta_tip` | Tips at opening angle |
|---|---|---|---|
| **A** | 5617 / 9315 = 0.603 | 37.1 deg | **127 deg** |
| B | 5617 / 8190 = 0.686 | 43.3 deg | 133 deg |
| B+ | 4551 / 8190 = 0.556 | 33.8 deg | 124 deg |

The selected construction is already usable past normal laptop angles
(100-120 deg) with no mitigation at all. What it lacks is margin — this is the
*static* threshold, with nothing allowed for tapping the screen, knocking the
desk, or lap use.

## Result 2 — rear setback

Design target: stable to 150 deg opening (`theta = 60`, `sin = 0.866`).

```
s >= (M_lid * r_lid * sin(theta) - M_base * d_base) / (M_base + M_lid)
```

| Case | `s` for 150 deg | `s` for 135 deg | `s` to never tip |
|---|---|---|---|
| **A** | **7.1 mm** | **2.8 mm** | **10.8 mm** |
| B | 4.6 mm | 0.9 mm | 8.1 mm |
| B+ | 8.7 mm | 4.2 mm | 12.6 mm |

The last column solves for the restoring moment exceeding the largest overturning
moment the lid can produce at any angle (`theta = 90 deg`, lid flat back at
180 deg):

```
s_never = (M_lid * r_lid - M_base * d_base) / (M_base + M_lid)
        = (9315 - 5617) / 344  =  10.75 mm
```

[ADR-0006](../adr/0006-rear-edge-io-vs-hinge.md) independently wants **10 mm** of
setback as a shelf for the keyboard's rear-edge I/O, which is very nearly there.
At `s = 10` exactly:

```
restoring  = 5617 + 10 * 344 = 9057
max overturning = 207 * 45   = 9315
sin(theta_tip)  = 9057 / 9315 = 0.9723  ->  76.5 deg  ->  tips at 166.5 deg
```

So 10 mm gives stability to 166 deg, which is past any plausible use, and
**15 mm** eliminates tipping across the entire mass bracket, which is what
[ADR-0003](../adr/0003-lid-balance-strategy.md) decided. The extra millimetres
are free in mass and thickness and cost only footprint depth.

Treat "cannot tip" as a margin statement, not a guarantee: it holds only to the
extent the estimated masses and CoM positions hold, and it says nothing about
being knocked sideways or used on a lap.

## Result 3 — counterweight

Ballast in the front lip of the base, arm ~82 mm forward of the hinge:

```
m = (M_lid * r_lid * sin(theta) - M_base * d_base) / arm
```

| Case | Mass for 150 deg | for 135 deg | to never tip, at `s = 10` |
|---|---|---|---|
| **A** | **30 g** | **12 g** | **3.1 g** |
| B | 18 g | 4 g | 0 g |
| B+ | 31 g | 15 g | 21 g |

If the setback stays at 10 rather than going to 11, about **3 g** in the ballast
pocket closes the same gap — a steel strip of roughly 190 x 3 x 1.5 mm, or
frankly a couple of coins.

Either way the pocket is retained, empty, as insurance: every mass in the tables
above is an `E` estimate, and the pocket is the only lever that still works after
the geometry is cut. It sits in the front of the wedge, where the closed stack is
18.3 against the governing 22.2, so it costs no closed height. Brass (8.5) or
tungsten (19.3) shrink any given mass further.

## Result 4 — limit the opening angle

A hard stop at 120 deg makes the problem vanish at zero cost, at the price of
never reclining the screen. The honest answer if the 10 mm of footprint turns out
to matter.
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

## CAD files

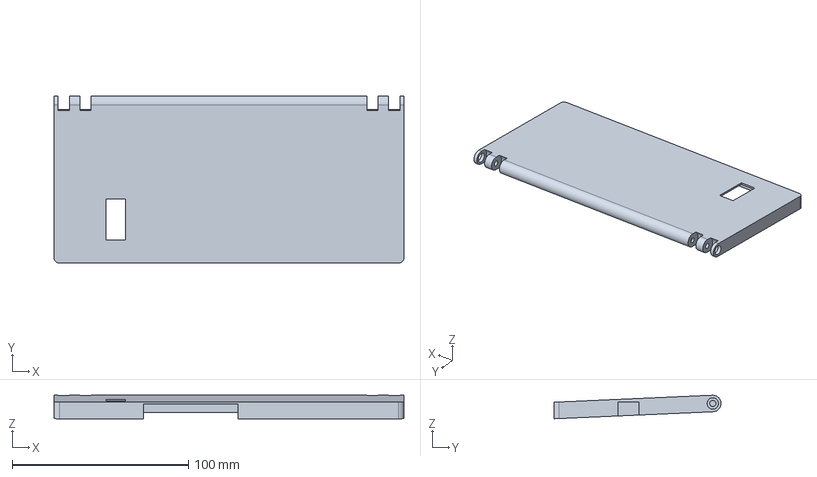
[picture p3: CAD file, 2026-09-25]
export/mk3-lid.step
198.4 x 94.7 x 13.4 mm

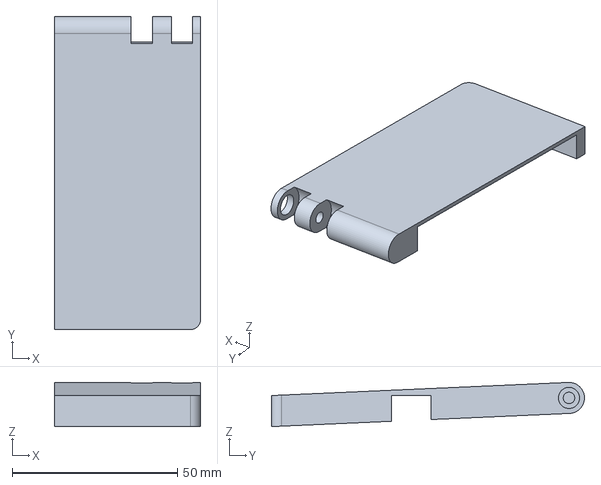
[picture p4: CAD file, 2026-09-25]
export/mk3-coupon21-lid.step
44.2 x 94.7 x 13.4 mm

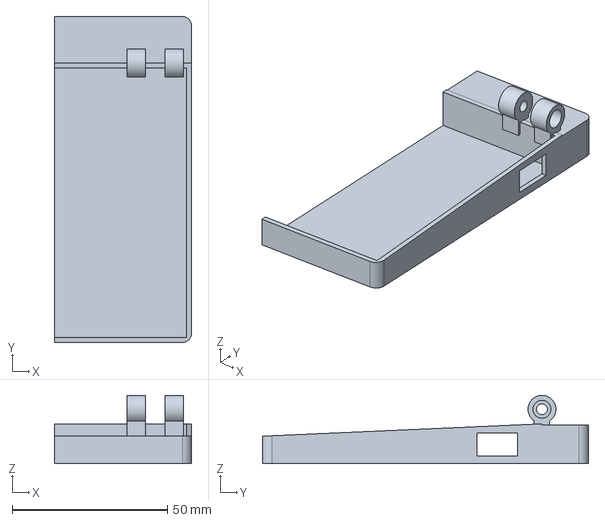
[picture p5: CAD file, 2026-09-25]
export/mk3-coupon21-base-plainnut.step
44.2 x 105.0 x 22.0 mm

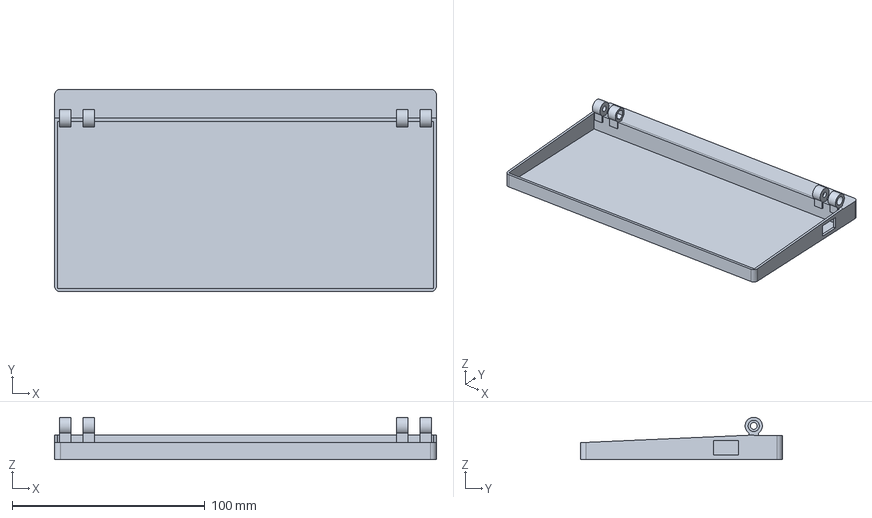
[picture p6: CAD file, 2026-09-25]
export/mk3-base.step
198.4 x 105.0 x 22.0 mm

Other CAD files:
export/mk3-coupon21-base.step
export/mk3-base-plainnut.step
export/mk3-base-plainnut.stl
export/mk3-base.stl
export/mk3-coupon21-base-plainnut.stl
export/mk3-coupon21-base.stl
export/mk3-coupon21-lid.stl
export/mk3-lid.stl

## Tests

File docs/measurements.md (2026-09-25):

# Measurements

All dimensions in mm, masses in g. Axis convention used throughout the project:

- **X** — span, left-to-right along the key rows (the long axis)
- **Y** — depth, front-to-back (user's body towards the hinge)
- **Z** — height, table to top of the closed device

Confidence tags: `M` measured with calipers, `S` from spec sheet / open sources,
`E` estimated or derived, `?` unknown, must be captured.

## Keyboard — Jomaa KEYBOARD098RU "Ardor Plum"

Bluetooth keyboard, Russian layout, salvaged from its folio case (case discarded).

| Property | Value | Conf |
|---|---|---|
| Span (X) | 194.00 (first reading 193.00; re-measured when it would not go into a printed pocket) | M |
| Depth (Y) | 86.25 | M |
| Height, shell only, rear edge (thickest) | 9.52 | M |
| Height, shell only, front edge (thinnest) | 5.54 | M |
| Height incl. keycaps, rear edge | 11.34 | M |
| Keycap protrusion above shell, rear | 1.82 (design value 2.0) | M |
| Keycap protrusion above shell, front | 1.82 | M | owner: same as rear |
| Mass | 95 | M |
| Bottom face | flat, with a perimeter rim 1.68 wide and < 1.0 tall | M |
| Top face | wedge, rises front → rear | M |
| Wedge angle (derived) | atan((9.52-5.54)/86.25) = 2.64 deg | E |

### I/O

The rear (thick) edge carries the OFF/ON slide switch and the four status LEDs —
see `reference/photos/keyboard-rear-edge-switch-leds.jpg`.

**The USB-C port is on the keyboard's RIGHT SIDE face**, not on the rear edge.
`reference/photos/keyboard-rear-edge-usb-c.jpg` shows that face, and an earlier
reading of it as the rear edge seen at an angle was wrong. That misreading
invented the hinge-versus-I/O conflict that
[ADR-0006](adr/0006-rear-edge-io-vs-hinge.md) existed to solve.

> `reference/` is gitignored — the photos and borrowed models in it are local
> only and do not travel with a clone. Every dimension they support is recorded
> in this file; the images are corroboration, not the source of record.

Datums: distance measured **back from the keyboard's rear (high) edge** along the
right side face; Z from the plane the keyboard rests on.

| Feature | Value | Conf |
|---|---|---|
| USB-C, rear edge to the near end of the connector | 8.00 | M |
| USB-C opening, lower edge above the rest plane | 3.00 | M |
| USB-C opening, upper edge below the top of that face | 2.00 | M |
| Side face height at the port (derived, the face is a wedge) | 8.94 | C |
| USB-C opening height (derived) | 3.94 | C |
| USB-C opening width, along the keyboard's depth | assumed 9.0 | ? - confirmed by fit |
| OFF/ON slide switch | rear edge, not needed | D |
| LEDs x4 | rear edge, not needed | D |

In device coordinates the opening centres on **Y 75.65, Z 6.17**, in the base's
right wall.

Two things worth a second look: the assumed 9.0 opening width, and whether the
3 and 2 were taken to the visible opening or to the connector housing.

The switch stays permanently ON and the LEDs are not required to be visible, so
**USB-C is the only feature on this edge needing access** — see
[ADR-0006](adr/0006-rear-edge-io-vs-hinge.md) and F5.

**Height matters as much as X.** The hinge axis sits at 12.54 above the desk and
the keyboard's rear face tops out at 10.72, so a port mounted high on that face
cannot share an X position with a hinge station — see R1 in
[plan.md](plan.md). Tasks 0.1 and 0.1b.

**Task 0.1 is closed by fit, not by callipers (2026-09-22).** The first printed
coupon's window lines up with the real keyboard's port, so the assumed 9.0 never
has to become a measurement. The tolerance was worked out beforehand and is
recorded next to the parameter: the opening spans 6.0 to 19.0 back from the
keyboard's rear edge, against a measured 8.00 where the connector starts, so any
true width up to 11.0 is cleared with 2.0 to spare at the rear end. A USB-C
receptacle is 8.34.

This edge is also the natural hinge edge, which is a direct conflict — see
[ADR-0006](adr/0006-rear-edge-io-vs-hinge.md).

### Not yet known (requires teardown)

| Property | Conf |
|---|---|
| Thickness of the keyboard's own bottom shell | ? |
| Thickness of plate + PCB + scissor stack (flat portion) | ? |
| Battery size and location | ? |
| Whether the wedge is pure shell or follows internal parts | ? |

These gate [ADR-0002](adr/0002-keyboard-integration-depth.md).

## Phone — Google Pixel 3a XL

| Property | Value | Conf |
|---|---|---|
| Body | 160.1 x 76.1 x 8.2 | S |
| Envelope incl. camera bump (from Mk2 STL) | 160.1 x 77.1 x 9.4 | E |
| Mass | 167 | S |
| Screen | 6.0" 18:9, used in landscape | S |
| USB-C | bottom edge (short edge) | S |
| Fingerprint reader | rear face, upper third | S |
| Power + volume buttons | right edge in portrait; top long edge of the lid once mounted | S |
| 3.5 mm jack | top edge in portrait; left short edge of the lid — no cutout, unused | S |
| SIM tray | left edge in portrait; hinge-side edge of the lid | S |
| Button positions along the edge, and protrusion | — | ? |
| USB-C position on the short edge | assumed centred | A |
| Front bezel width | not needed | D | no retention lips; the phone is taped in |
| Camera bump height | — | ? | not needed: the cutout is a through-hole |

Orientation is fixed by the requirement that power and volume stay reachable —
see [ADR-0004](adr/0004-phone-retention.md). Edge assignments above assume it.

A reusable solid model exists: `../palmtop_mk2/Pixel_3A_XL_Body.stl`.

## Mk2 reference (the device being replaced)

| Property | Value | Conf |
|---|---|---|
| Footprint | 170.0 x 91.4 | M (from STL) |
| Lid phone pocket | Y -38.55 .. +38.55 | M (from STL) |
| Lid wall, button edge | **4.70** | M (from STL) |
| Lid wall, hinge edge | **9.60** | M (from STL) |
| Button window | **54.0 x 10.0**, at X -48.6 .. +5.0 | M (from STL) |
| Camera cutout | 11.2 x 23.2, at X -69.8 .. -58.6, Y -29.2 .. -6.0 | M (from STL) |

Both the button window and the camera cutout transfer to Mk3 by referencing them
to the **phone's own edges** rather than the lid's, since the two lids differ in
depth and in how the phone sits in them. X transfers unchanged, both lids
centring the same phone on X = 0.

**Mk2 biased the phone forward in the lid** — a thin wall where the buttons are,
a thick one on the hinge side — and cut **one window over both buttons** rather
than two holes. Mk3 does the same. Since both lids centre the same phone in X in
the same orientation, Mk2's window span transfers directly and task 0.10 stops
being a blocker.
| Base part height | 23.35 | M (from STL) |
| Lid part height | 18.21 | M (from STL) |
| Closed height, assembled | ~32 | ? |

The two printed parts interleave at the hinge, so the closed height is less than
the sum. **Action: measure the physical Mk2 with calipers** — this is the number
Mk3 is benchmarked against.

## Print material

| Property | Value | Conf |
|---|---|---|
| Material | PETG (as Mk2) | E |
| Density | 1.27 g/cm3 | S |

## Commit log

2026-09-20 Design record and parametric model for Mk3
    Establishes the project: requirements, measurements, four analyses, nine ADRs,
    and a build123d model that builds both halves and checks itself against them.
    Design point: 22.24 mm closed at the rear, 18.26 at the front, on a 196.8 x
    105.05 footprint. Mk2 is roughly 32 mm.
    Decisions taken (docs/adr):
    - 0002 keyboard stays sealed; stripping it deferred to Mk4
    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
    [mk3-base.step, mk3-base.stl, mk3-coupon21-base.step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]
2026-09-22 Fix two defects the first coupon print found
    Printing coupon 2.1 surfaced two faults that every existing check had
    passed, both of the same kind: geometry that is correct and assemblies
    that are impossible.
    Detached lid knuckles. The lid exported as four solids - the shell plus
    three loose rings of 0.313 cm3 - and the middle ring lifted off the bed
    during the print. station_envelope cut the 11.4 relief across the whole
    18.2 station width, including the middle band where the lid's own
    knuckle lives; with a relief radius of 5.70 against a knuckle radius of
    4.50, what was added back floated with 1.20 of clearance all round. The
    relief now clears only the two outer bands, and the middle band ke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
    [mk3-base.step, mk3-base.stl, mk3-coupon21-base.step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]
2026-09-22 Close the USB-C width measurement by fit
    The first printed coupon's window lines up with the real keyboard's
    port, so kbd_usbc_w comes off the BLOCKED list without ever becoming a
    callipered number. It does not need to be one: the opening spans 6.0 to
    19.0 back from the keyboard's rear edge against a measured 8.00 where
    the connector starts, so any true width to 11.0 is cleared, and a USB-C
    receptacle is 8.34.
    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
    [mk3-base.step, mk3-coupon21-base.step, mk3-coupon21-lid.step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]
2026-09-25 Open the phone USB-C slot, nylon-insert nut, per-station torque
    Phone USB-C. The tunnel through the lid's right side spacer had a
    0.73 mm roof on the screen side: a 12 x 18 mm bridge that sagged into
    the opening when the lid printed face-down, and the first coupon would
    barely pass a cable. The cut now runs out through the screen face, so
    there is no bridge; the plug lays in from that side, and with the lid
    shut the slot faces the keyboard. The floor side is unchanged at 1.68,
    which leaves 3.5 below the port centre as the one limit on overmould
    thickness.
    Nut. The pocket is 4.30 deep for a DIN 985 nylon-insert nut instead of
    2.70 for a plain DIN 934 with threadlocker. The O-ring keeps prelo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
    [mk3-base-plainnut.step, mk3-base-plainnut.stl, mk3-base.stl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]
2026-09-25 Add renders to the README and license under CERN-OHL-S-2.0
    cad/render.py draws the two README images straight from model.build():
    a small numpy z-buffer rasteriser with per-face smooth normals, outlines
    where the part changes, the depth jumps or the surface creases, and a
    soft contact and cast shadow on the ground. No new dependencies - numpy
    and PIL were already in the venv. The phone and keyboard are stand-ins
    built from their measured envelopes and placed where the pockets put the
    real ones, so the picture reads as a device rather than two empty shells.
    The README had drifted from the design it describes: it called cad/
    FreeCAD sources, gave the hinge three or four stations at 0.091 N*m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
2026-09-25 Widen the keyboard pocket to the re-measured span
    The first full base would not take the keyboard: both long walls bowed out
    toward mid-span. The keyboard is 194.0 across, not 193.0, and the printed
    pocket came out 193.0 against 193.6 modelled.
    Span clearance is now its own parameter, clr_kbd_x = 0.60 per side, so the
    pocket models at 195.2 and should print near 194.6. Depth keeps clr_kbd at
    0.30, which fitted. The device grows 1.6 wide, to 198.4; thickness, hinge
    and stations are unchanged, and all checks pass.
    [mk3-base-plainnut.step, mk3-base-plainnut.stl, mk3-base.step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]
